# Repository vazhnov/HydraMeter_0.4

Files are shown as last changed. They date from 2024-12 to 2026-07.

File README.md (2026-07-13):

# HydraMeter_0.4

Open source [multimeter](https://en.wikipedia.org/wiki/Multimeter)

## Intro

I don't have detailed assembly documents yet, and this isn't really well made for easy assembly in any case, it's a proof of concept at the moment.

There are some more details here: https://hackaday.io/project/176607-hydrameter but it's not much. Mainly a few entries down there's a tour
of how the analog stuff works: https://hackaday.io/project/176607-hydrameter/log/223270-schematic-and-operation

## Repository structure

* Directory [MMTR_AFE_00_04_TORELEASE](./MMTR_AFE_00_04_TORELEASE) contains all schematics and board layouts.
* Directory [MMTR_V00_03_Case](./MMTR_V00_03_Case) contains all the CAD, source type is solidedge (they have a free community edition).
* Directory [Code -> HackBoard_V02_10_shbrd_cal](./Code/HackBoard_V02_10_shbrd_cal/) contains the code for the analog frontend.
* Directory [Code -> Display_VP_10_WirelessV2_SC](./Code/Display_VP_10_WirelessV2_SC/) contains code for the display section.

## Notes

I would recommend 24 to 28 AWG stranded wire for connecting to switches, except the mA/uA switch, for which I'd use 20AWG.
The switches should pull inputs to the 74165s to ground, for numbering you'll have to check the code (or adjust it), when assembled I just
wired up all of them then recorded which switch went where, I don't have a list or diagram. On the board these are labeled A-H, one set
is near the middle of the board, the other next to the module connector.

Hardwired connections are: the two ohms jumpers (J7 and J8) are wired to the second pole of the lower-right switch (right from the front),
and the mA/uA switch goes to J5 and J6.

There's a hardwired connection from J30 to J34, which should be made with at least 18AWG wire, as it carries the full current for the 10A range.

## Tweaks

Note that this version of the PCB has some tweaks from the last manufactured version,
these have not been verified to work.

The as-made PCB is under version 0.3,
however, this version requires significant manual rework including:
* pullup resistors for all switches to D3V3
* cutting jumpers to the Module outputs (J96-99, to configure them as inputs), and wiring switches to them
* additional capacitors on D3V3 to D0V, to stabilize the rail when using a radio module
* DNP U5, and bridge pin 3 to pin 4
* DNP: R74, D5, C72, R76, R77, U26, R78, Q20, Q21, R80, R79
* Replace R33 with a ~16K resistor, or two 33K in parallel
* Manually cut the trace going to pin 10 on U12, U13 and U16 (pulling it to D0V), and wire that pin on the chip to D3V3
* U18 has the wrong footprint (SOIC-16 used on the board, the actual chip is a SOIC-14).
* Angle U18 such that only pins 14-9 make contact with the board (so pins 1-7 are above the surface), and solder in place.
* Then manually wire pins 2-7 to the appropriate pads with short wires.
* If using a battery, a protected cell must be used, there is no circuitry onboard to protect from over or under voltage.
* Positive should be soldered to J10, negative to J11.

To charge, two diodes can be placed in series from VBUS on the
PI pico (MCU_VBUS) to battery positive (charging the battery when USB is plugged in). Bypassing one of the diodes with
a 50 or 100 ohm resistor can improve charge time. This however WILL overcharge the battery if proper cell protection
is not in place! This is a terrible hack solution I used to get something working in like an hour. Use a charger IC
or board or something.

## License

This project uses the CERN Open Hardware Licence Version 2 - Strongly Reciprocal.
Any derived works must fall under the same license and must be open source themselves.

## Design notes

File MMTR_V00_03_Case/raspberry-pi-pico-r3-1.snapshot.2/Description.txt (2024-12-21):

Raspberry Pi Pico-R3

Link to CAD models:
https://grabcad.com/library/raspberry-pi-pico-r3-1

The first micro controller offered from the Raspberry Pi foundation. 

The software support and documentation are solid.  I will try to use it in a few projects.
https://www.raspberrypi.org/products/raspberry-pi-pico/

It's nice that it is programmable in both MicroPython and C++.
MicroPython files can be dragged and dropped to work right away, but I'm not sure if the same can be done for C/C++ files.

I was hoping for better deep sleep currents and idle power usage and also WiFi like the ESP32. Also a USB Type C connector in 2021 would have been nice.

I hope they take inspiration from the Tiny Pico (low power usage ESP32) and its good low power features.

https://www.tinypico.com/

#CAD #SolidWorks #3dmodel #microcontroller #raspberrypipico

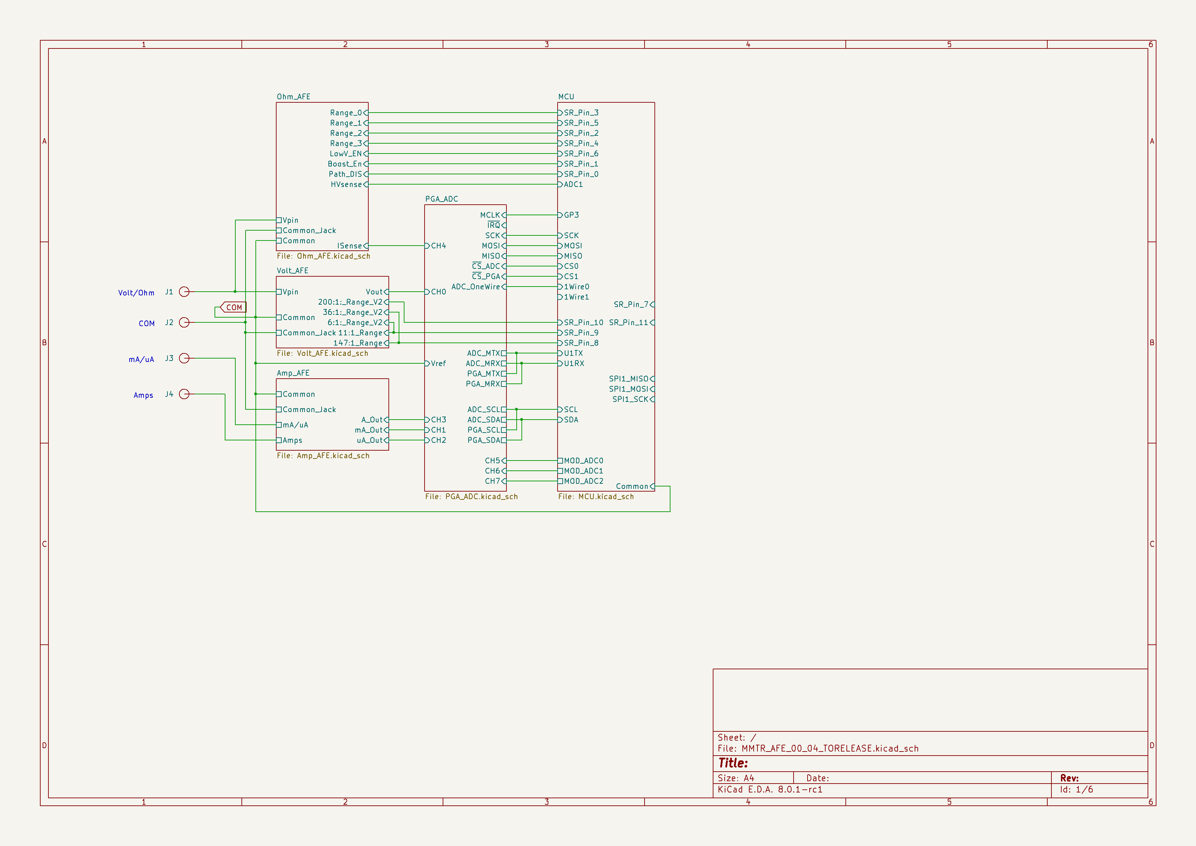
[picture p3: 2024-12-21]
MMTR_AFE_00_04_TORELEASE/Schematic_PDF_and_Pics/Root.png

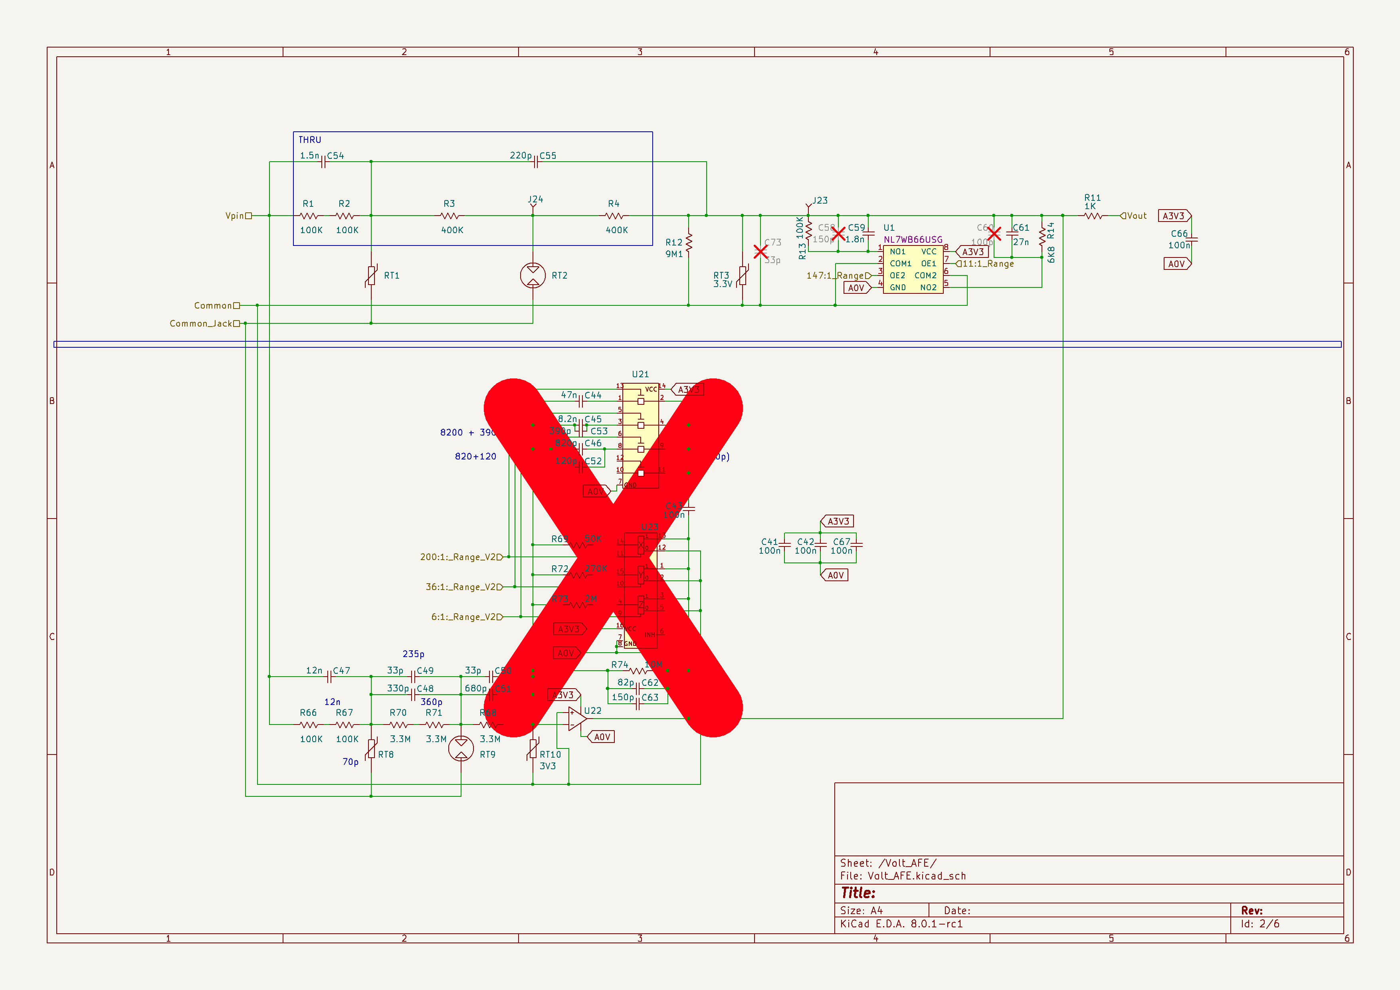
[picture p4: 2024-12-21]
MMTR_AFE_00_04_TORELEASE/Schematic_PDF_and_Pics/Volt_AFE.png

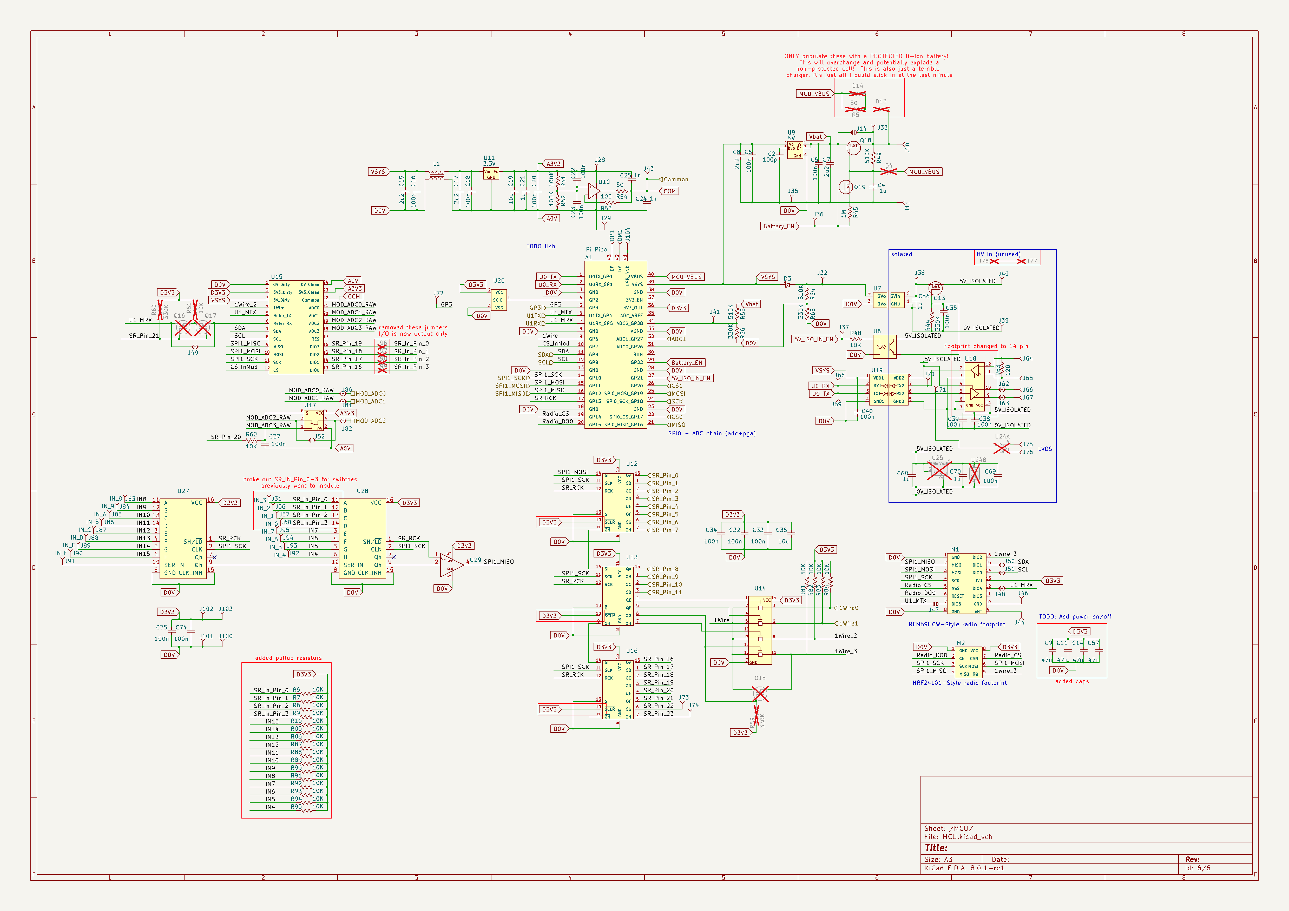
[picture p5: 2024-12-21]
MMTR_AFE_00_04_TORELEASE/Schematic_PDF_and_Pics/MCU.png

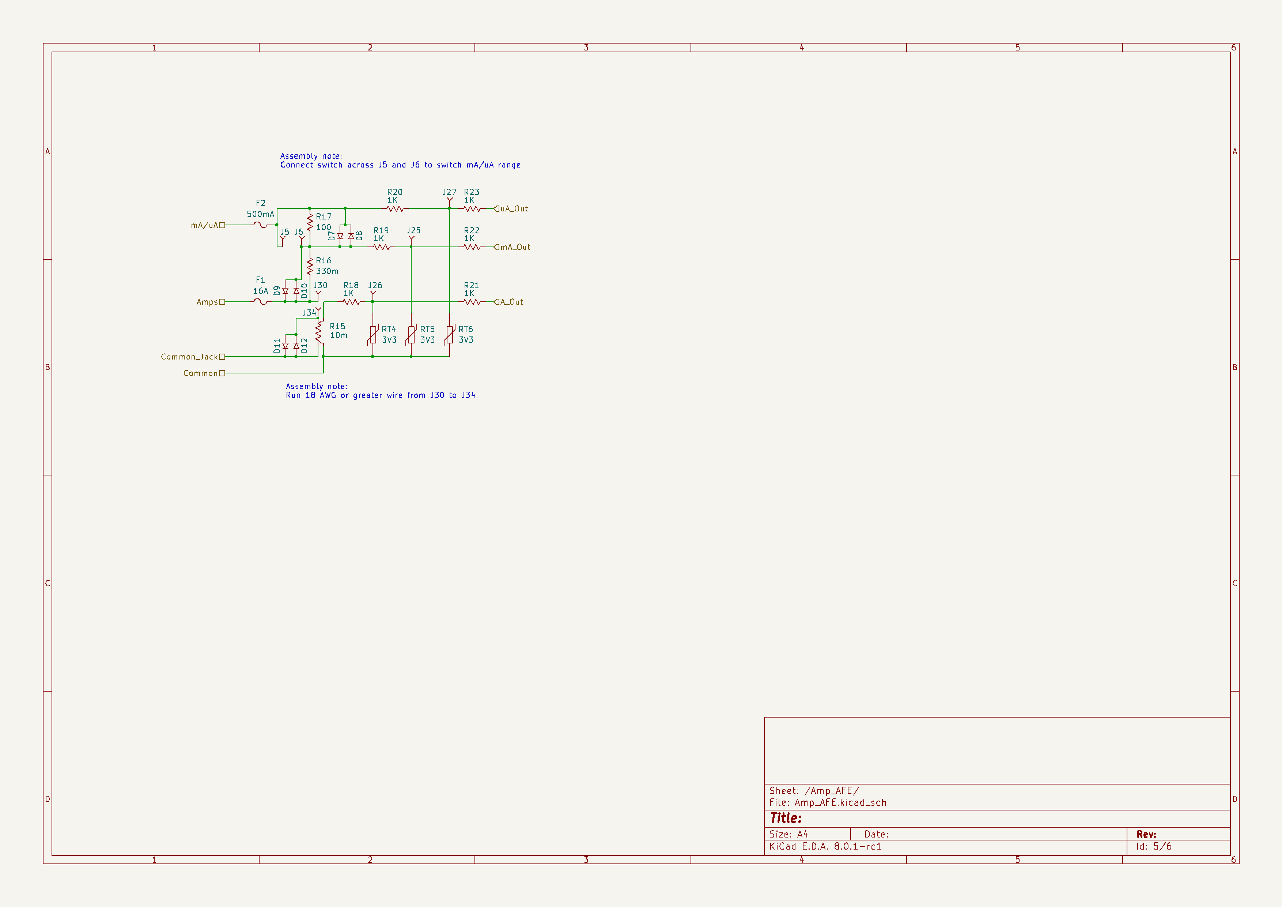
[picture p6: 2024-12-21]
MMTR_AFE_00_04_TORELEASE/Schematic_PDF_and_Pics/Amp_AFE.png

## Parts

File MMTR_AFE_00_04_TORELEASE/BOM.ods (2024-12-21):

Quantity | Digi-Key Part # | Manufacturer Part Number | Description | Unit Price | Extended
2 | 283-MSMA2512R0100FENCT-ND | MSMA2512R0100FEN | RES 0.01 OHM 1% 2W 2512 | $0.57000 | $1.14
4 | CG0603MLU-3.3ECT-ND | CG0603MLU-3.3E | VARISTOR 0603 | $0.35800 | $1.43
1 | 495-2596-1-ND | B72510T0110K062 | VARISTOR 18V 120A 0805 | $0.42000 | $0.42
1 | MCP6S28-I/SL-ND | MCP6S28-I/SL | IC OPAMP PGA 8 CIRCUIT 16SOIC | $3.04000 | $3.04
1 | 150-MCP3461R-E/ST-ND | MCP3461R-E/ST | IC ADC 16BIT SIGMA-DELTA 20TSSOP | $2.38000 | $2.38
1 | 1528-1066-ND | 1206 | SMT ADAPTERS 3 PACK 20SOIC/TSSOP | $4.50000 | $4.50
2 | DMP3099L-7DICT-ND | DMP3099L-7 | MOSFET P-CH 30V 3.8A SOT23 | $0.25200 | $0.50
6 | 4878-MMFTP84CT-ND | MMFTP84 | MOSFET P-CH 60V 130MA SOT23-3 | $0.17800 | $1.07
6 | MMBT3904TPMSCT-ND | MMBT3904-TP | TRANS NPN 40V 0.2A SOT23 | $0.09000 | $0.54
10 | 2N3904TAFSCT-ND | 2N3904TA | TRANS NPN 40V 0.2A TO92-3 | $0.28300 | $2.83
1 | 2725-B0309S-1WR3-ND | B0309S-1WR3 | DC DC CONVERTER 9V 1W | $1.82000 | $1.82
1 | 2725-B0305S-1WR3-ND | B0305S-1WR3 | DC DC CONVERTER 5V 1W | $1.82000 | $1.82
1 | 31-AP7375-33SA-7CT-ND | AP7375-33SA-7 | IC REG LIN 3.3V 300MA SOT23-3 | $0.41000 | $0.41
1 | 945-3159-ND | RFM-0505S | DC DC CONVERTER 5V 1W | $1.95000 | $1.95
1 | 2648-SC0915CT-ND | SC0915 | RASPBERRY PI PICO RP2040 | $4.00000 | $4.00
1 | LMR321G-GCT-ND | LMR321G-GTR | IC OPAMP GP 1 CIRCUIT 5SSOP | $0.45000 | $0.45
1 | 576-2575-1-ND | LMC7101BYM5-TR | IC OPAMP GP 1 CIRCUIT SOT23-5 | $0.62000 | $0.62
2 | A105968CT-ND | YR1B100KCC | RES 100K OHM 0.1% 1/4W AXIAL | $0.52300 | $1.05
1 | YAG1966CT-ND | RT0805BRD076K8L | RES SMD 6.8K OHM 0.1% 1/8W 0805 | $0.36000 | $0.36
1 | 311-9.10MFRCT-ND | RC1206FR-079M1L | RES 9.1M OHM 1% 1/4W 1206 | $0.03600 | $0.04
1 | 495-6548-1-ND | B72205S0231K311 | VARISTOR 360V 400A DISC 5MM | $0.46000 | $0.46
1 | 495-3205-ND | B32671L1152J000 | CAP FILM 1500PF 5% 1.6KVDC RAD | $0.60000 | $0.60
1 | 493-3481-ND | QYX2A272JTP | CAP FILM 2700PF 5% 100VDC RADIAL | $0.33000 | $0.33
1 | 486-7110-1-ND | 34.6062 | FUSE BOARD MNT 63MA 250VAC RAD | $0.38000 | $0.38
1 | 486-3324-ND | 8020.508 | FUSE CERAMIC 16A 500VAC 400VDC | $0.90000 | $0.90
4 | 507-FC-102BRIGHTTIN-ND | FC-102 BRIGHT TIN | FUSE CLIP CARTRIDGE 15A PCB | $0.18600 | $0.74
1 | 13-RT1206FRD07100RLCT-ND | RT1206FRD07100RL | RES SMD 100 OHM 1% 1/4W 1206 | $0.12700 | $0.13
1 | 738-RNCF1206DTE1R00CT-ND | RNCF1206DTE1R00 | RES 1 OHM 0.5% 1/4W 1206 | $0.33000 | $0.33
1 | BKCT2912-0-ND | CT2912-0 | CONN BANANA JACK SOLDER BLACK | $1.40000 | $1.40
3 | BKCT2912-2-ND | CT2912-2 | CONN BANANA JACK SOLDER RED | $1.40000 | $4.20
1 | 497-STISO621TRCT-ND | STISO621TR | DUAL CHANNEL DIGITAL ISOLATOR | $2.29000 | $2.29
1 | 36-2478-ND | 2478 | BATT HOLDER AA 4 CELL 6" LEADS | $1.97000 | $1.97
1 | NL7WB66USGOSCT-ND | NL7WB66USG | IC SWITCH SPST-NO X 2 10OHM US8 | $0.39000 | $0.39
1 | 160-1360-5-ND | LTV-816 | OPTOISOLATR 5KV TRANSISTOR 4-DIP | $0.390 | $0.39
1 | AP2210K-5.0TRG1DICT-ND | AP2210K-5.0TRG1 | IC REG LINEAR 5V 300MA SOT23-5 | $0.440 | $0.44
1 | 4816-WCM2012F2SF-361T03CT-ND | WCM 2012F2SF-361T03 | 2 LINE COMMON MODE CHOKE SURFACE | $0.120 | $0.12
10 | 1276-1075-1-ND | CL31A106KAHNNNE | CAP CER 10UF 25V X5R 1206 | $0.128 | $1.28
3 | CUS08F30H3FCT-ND | CUS08F30,H3F | DIODE SCHOTTKY 30V 800MA USC | $0.320 | $0.96
10 | DMN65D8L-7DICT-ND | DMN65D8L-7 | MOSFET N-CH 60V 310MA SOT23 | $0.124 | $1.24
1 | PI5A3157CEXCT-ND | PI5A3157CEX | IC SWITCH SPDTX1 13OHM SOT363-6 | $0.350 | $0.35
1 | 13-FMP100JT-52-1KCT-ND | FMP100JT-52-1K | RES 1K OHM 5% 1W AXIAL | $0.200 | $0.20
1 | 118-2045-14-BLF-ND | 2045-14-BLF | GDT 145V 10KA 2 POLE TH | $0.820 | $0.82
2 | 296-SN74HCS165PWRCT-ND | SN74HCS165PWR | 8-BIT PARALLEL-LOAD SHIFT REGIST | $0.450 | $0.90
1 | 74LVC1G126W5-7DICT-ND | 74LVC1G126W5-7 | IC BUFFER NON-INVERT 5.5V SOT25 | $0.310 | $0.31
2 | 1712-YR1B402KCCCT-ND | YR1B402KCC | RES 402K OHM 0.1% 1/4W AXIAL | $0.523 | $1.05
10 | 1655-1N4007FLCT-ND | 1N4007FL | DIODE GEN PURP 1KV 1A SOD123FL | $0.096 | $0.96
3 | 1727-3327-1-ND | 74HC595BQ,115 | IC 8BIT SHIFT REGISTER 16-DHVQFN | $0.353 | $1.06
1 | 1016-1834-1-ND | SP491EEN-L/TR | IC TRANSCEIVER FULL 1/1 14SOIC | $1.710 | $1.71
1 | 11AA080T-I/TTCT-ND | 11AA080T-I/TT | IC EEPROM 8KBIT SGL WIRE SOT23-3 | $0.300 | $0.30
1 | 1928-1294-ND | FKP2O102201D00JSSD | CAP FILM 220PF 5% 1KVDC RAD | $0.510 | $0.51
1 | 273-KDV12DR330ETCT-ND | KDV12DR330ET | RES 0.33 OHM 0.5% 1/2W 1206 | $0.350 | $0.35
1 | 490-6380-1-ND | GRM1885C1H182JA01J | CAP CER 1800PF 50V C0G/NP0 0603 | $0.055 | $0.06
1 | 1292-1425-1-ND | 0603B273K500CT | CAP CER 0.027UF 50V X7R 0603 | $0.052 | $0.05
1 | 495-3205-ND | B32671L1152J000 | CAP FILM 1500PF 5% 1.6KVDC RAD | $0.600 | $0.60
1 | 283-MSMA2512R0100FENCT-ND | MSMA2512R0100FEN | RES 0.01 OHM 1% 2W 2512 | $0.570 | $0.57
1 | 486-4156-ND | 8020.5068.G | FUSE CERM 1A 500VAC 500VDC 3AB | $0.660 | $0.66
1 | 2019-RN73R2BTTD5100B25CT-ND | RN73R2BTTD5100B25 | RES 510 OHM 0.1% 1/4W 1206 | $0.350 | $0.35
1 | 13-RE1206FRE0710KLCT-ND | RE1206FRE0710KL | RES SMD 10K OHM 1% 1/4W 1206 | $0.036 | $0.04
2 | 13-RT1206FRD07100KLCT-ND | RT1206FRD07100KL | RES SMD 100K OHM 1% 1/4W 1206 | $0.13 | $0.25
1 | 13-RE1206FRE071MLCT-ND | RE1206FRE071ML | RES SMD 1M OHM 1% 1/4W 1206 | $0.036 | $0.04
25 | RMCF0603FG1K00CT-ND | RMCF0603FG1K00 | RES 1K OHM 1% 1/10W 0603 | $0.009 | $0.22
25 | CR0603-FX-1002ELFCT-ND | CR0603-FX-1002ELF | RES SMD 10K OHM 1% 1/10W 0603 | $0.007 | $0.18
25 | RMCF0603FT100KCT-ND | RMCF0603FT100K | RES 100K OHM 1% 1/10W 0603 | $0.007 | $0.18
25 | RMCF0603FG1M00CT-ND | RMCF0603FG1M00 | RES 1M OHM 1% 1/10W 0603 | $0.007 | $0.18
25 | RMCF0603FT3K30CT-ND | RMCF0603FT3K30 | RES 3.3K OHM 1% 1/10W 0603 | $0.007 | $0.18
25 | RMCF0603FT33K0CT-ND | RMCF0603FT33K0 | RES 33K OHM 1% 1/10W 0603 | $0.007 | $0.18
25 | RMCF0603FT330KCT-ND | RMCF0603FT330K | RES 330K OHM 1% 1/10W 0603 | $0.007 | $0.18
25 | RMCF0603FT510KCT-ND | RMCF0603FT510K | RES 510K OHM 1% 1/10W 0603 | $0.009 | $0.22
1 | Usb C adapters | Female | https://www.amazon.com/ANMBEST-Connector-Receptacle-Adapter-Support/dp/B09WCSF8FC/ref=sr_1_4
1 | RS485/422 dev board |  | https://www.amazon.com/Max485-Chip-RS-485-Module-Raspberry/dp/B00NIOLNAG/ref=sr_1_2
1 | 12864 LCD screen (ST7565) | Select Gray Screen | https://www.aliexpress.us/item/3256805974305629.html
1 | 8.5 x 13.5 Rocker Switches (5pk) | Select 8.5 x 13.5 | https://www.aliexpress.us/item/2255800845721307.html
1 | Tiny Li-po battery WITH protection circuit | Select 1 | https://www.aliexpress.us/item/3256805609393649.html
2 | Radio Module | Select NRF24L01 DIP | https://www.aliexpress.us/item/3256805987194394.html
1 | 5 pk of DPST rocker switches | Select Black No Lamp | https://www.aliexpress.us/item/3256805717784088.html
4 | DPDT rocker switches | Select 6 pin On-Off-On | https://www.aliexpress.us/item/3256803299490563.html
1 | SPDT Momentary Rocker switch | Select 3 pin Self reset | https://www.aliexpress.us/item/3256803299490563.html

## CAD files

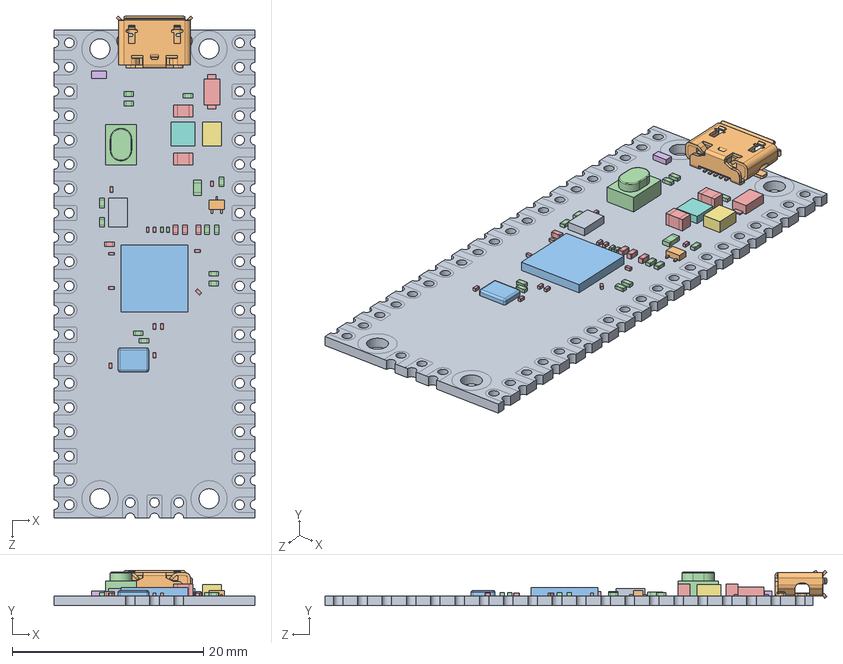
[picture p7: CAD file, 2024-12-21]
MMTR_V00_03_Case/raspberry-pi-pico-r3-1.snapshot.2/Raspberry Pi Pico-R3.SLDASM
21.0 x 3.69 x 52.4 mm
PCB, Raspberry Pi Pico-R3
MicroUSB Port, Raspberry Pi Pico-R3
RP2040 Microcontroller, Raspberry Pi Pico-R3
SW1, Tact Switch, Raspberry Pi Pico-R3
D1, Diode, Schottky, Raspberry Pi Pico-R3
D2, QSME-C194, LED, Raspberry Pi Pico-R3
L1, Inductor, Raspberry Pi Pico-R3
U2, RT6150B-33GQW, Buck Boost Converter, Raspberry Pi Pico-R3
U3, W25Q16JVUXIQ, Serial NOR Flash 16 Mbit, Raspberry Pi Pico-R3
Q1, MOSFET, DMG1012T, Raspberry Pi Pico-R3
X1, X12M000000S096, 12 Mhz Crystal Resonator, Raspberry Pi Pico-R3
SMD Resistor, Configurable, Raspberry Pi Pico-R3 x 15
SMD Capacitor, Configurable, Raspberry Pi Pico-R3 x 18

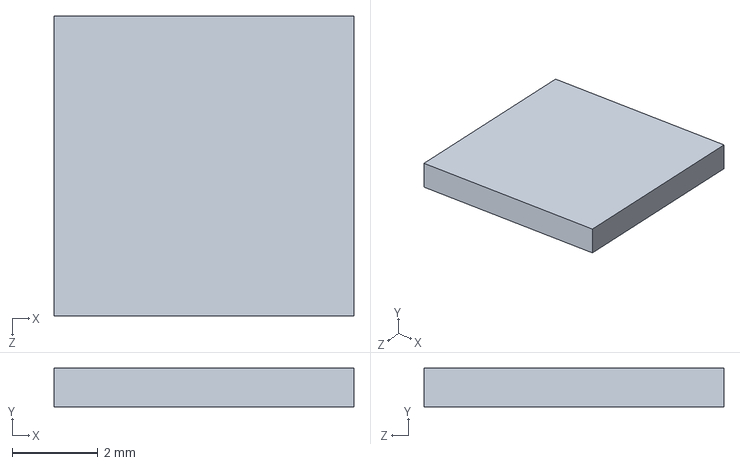
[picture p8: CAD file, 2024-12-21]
MMTR_V00_03_Case/raspberry-pi-pico-r3-1.snapshot.2/RP2040 Microcontroller, Raspberry Pi Pico-R3.SLDPRT
7.00 x 0.9 x 7.00 mm

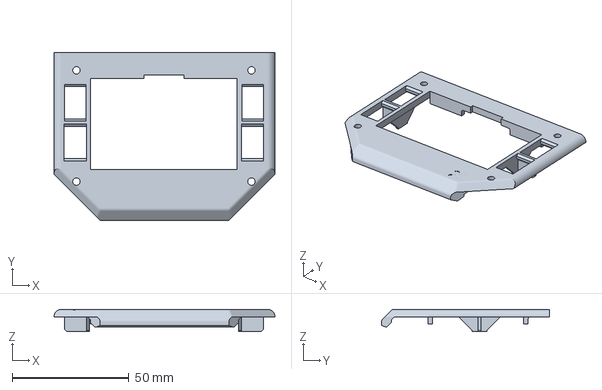
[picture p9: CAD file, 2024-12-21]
MMTR_V00_03_Case/ScreenCover_00_03_24_10_24_125.3mf
94.6 x 71.9 x 9.52 mm

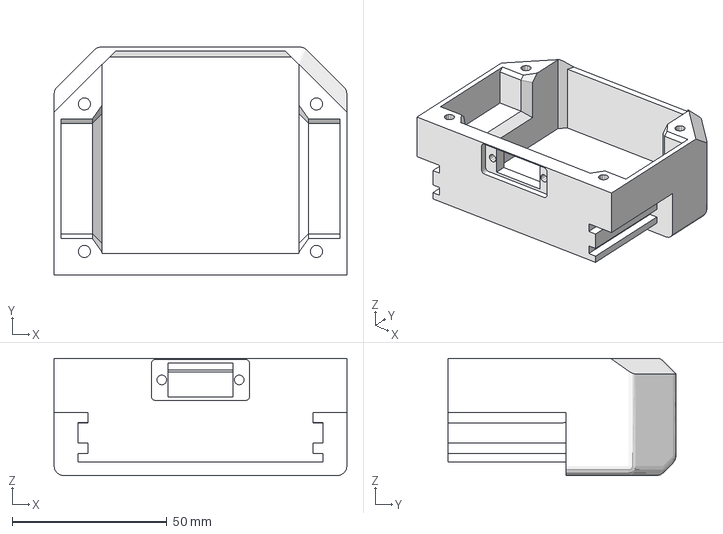
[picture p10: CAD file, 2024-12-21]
MMTR_V00_03_Case/Case_Upper_Dovetail_00_03_24_10_15_1353.3mf
94.6 x 73.7 x 37.9 mm

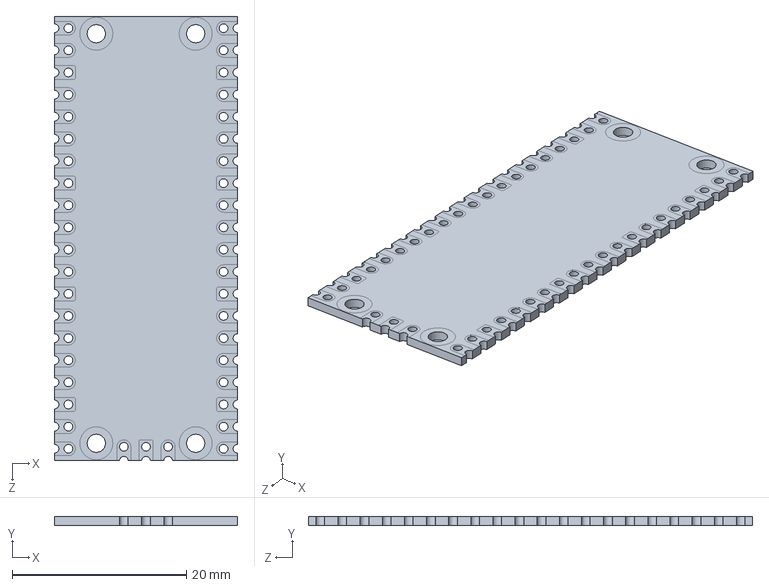
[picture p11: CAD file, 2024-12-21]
MMTR_V00_03_Case/raspberry-pi-pico-r3-1.snapshot.2/PCB, Raspberry Pi Pico-R3.SLDPRT
21.0 x 1.00 x 51.0 mm

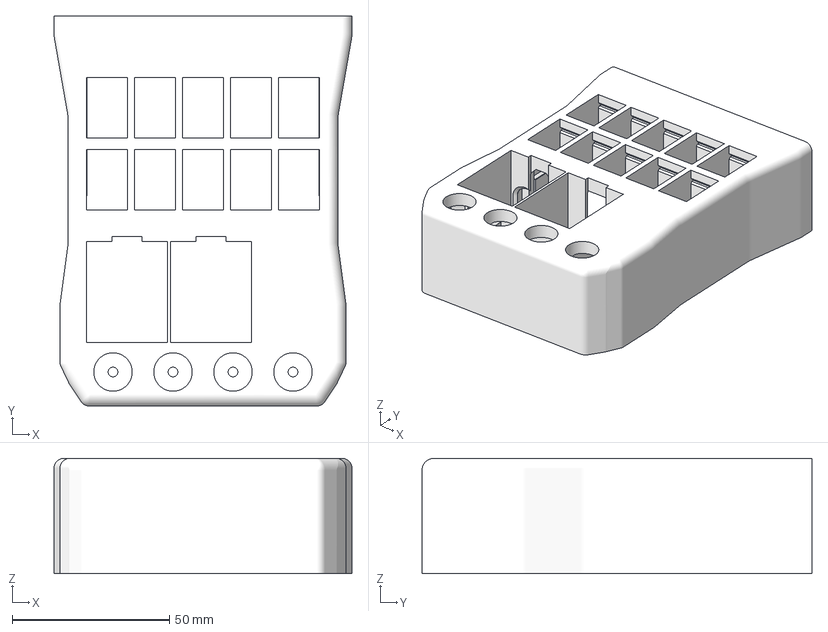
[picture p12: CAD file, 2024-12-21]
MMTR_V00_03_Case/Case_Top_00_03_24_10_16_2419.3mf
94.6 x 123.8 x 36.6 mm

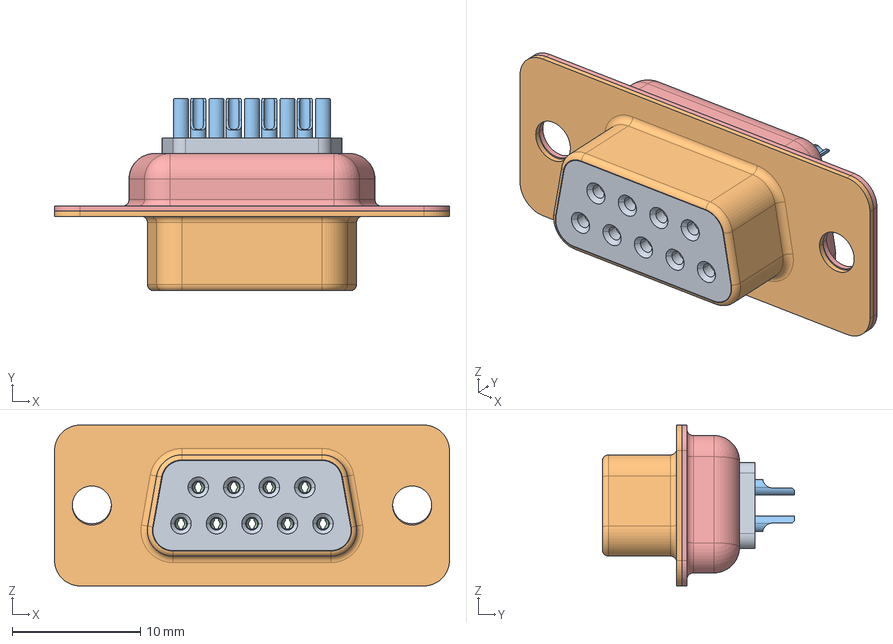
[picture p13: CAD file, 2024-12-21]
MMTR_V00_03_Case/l77sde09s-4.stp
30.8 x 15.0 x 12.6 mm
100-09HOUSING
100-09FEMALE-FRONTSHELL
104-FEMALE-TERMINAL-SHORT x 9
100-09FEMALE-BACKSHELL5555

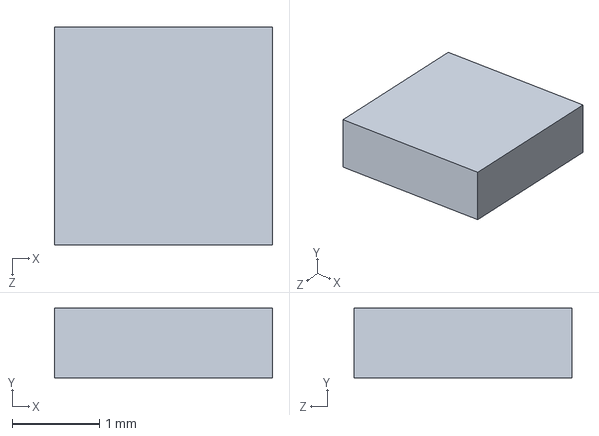
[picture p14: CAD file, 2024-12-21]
MMTR_V00_03_Case/raspberry-pi-pico-r3-1.snapshot.2/U3, W25Q16JVUXIQ, Serial NOR Flash 16 Mbit, Raspberry Pi Pico-R3.SLDPRT
2.50 x 0.8 x 2.50 mm

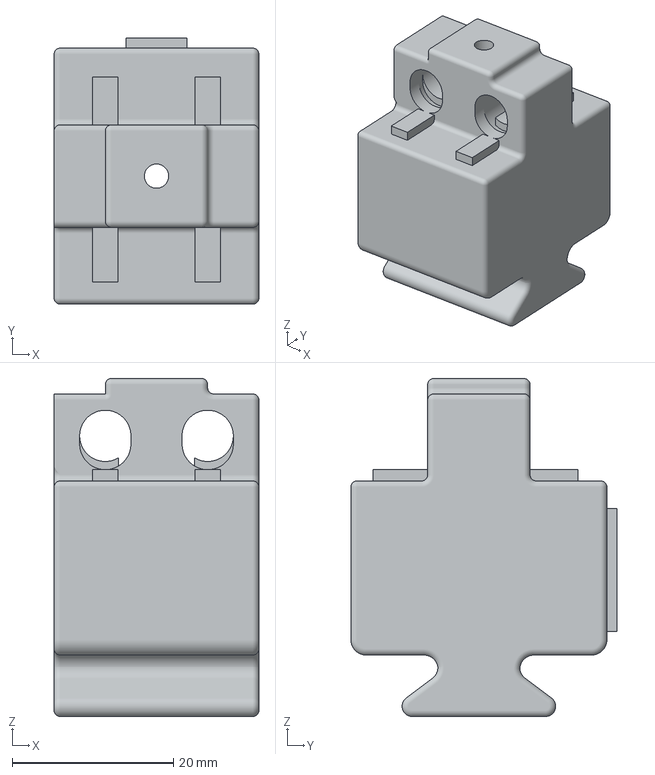
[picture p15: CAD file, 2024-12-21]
MMTR_V00_03_Case/Fuse_Holder_00_03_24_10_29.3mf
25.4 x 33.0 x 41.9 mm

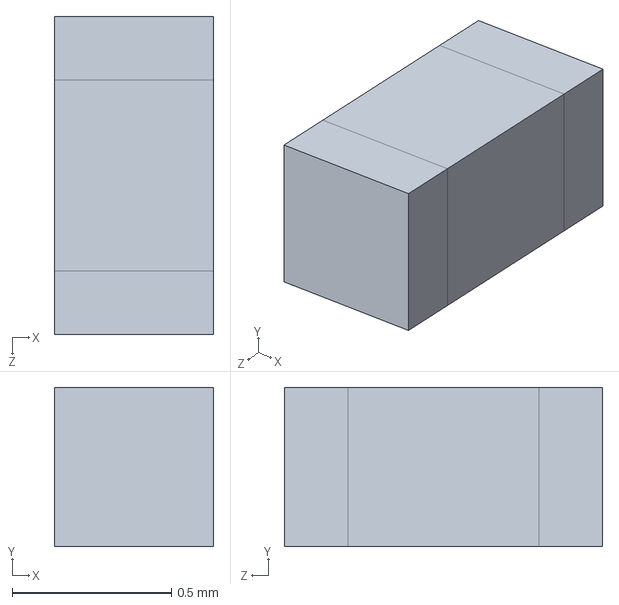
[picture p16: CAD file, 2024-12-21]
MMTR_V00_03_Case/raspberry-pi-pico-r3-1.snapshot.2/SMD Capacitor, Configurable, Raspberry Pi Pico-R3.SLDPRT
0.5 x 0.5 x 1.00 mm

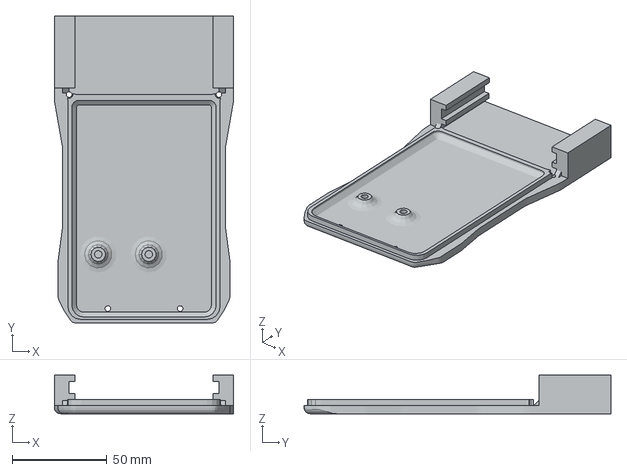
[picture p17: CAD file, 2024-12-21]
MMTR_V00_03_Case/Case_Bottom_00_03_24_10_15_1353.3mf
94.6 x 161.9 x 20.3 mm

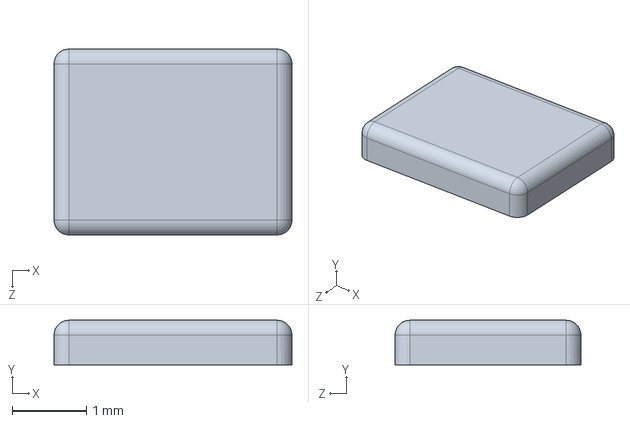
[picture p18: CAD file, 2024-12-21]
MMTR_V00_03_Case/raspberry-pi-pico-r3-1.snapshot.2/X1, X12M000000S096, 12 Mhz Crystal Resonator, Raspberry Pi Pico-R3.SLDPRT
3.20 x 0.6 x 2.50 mm

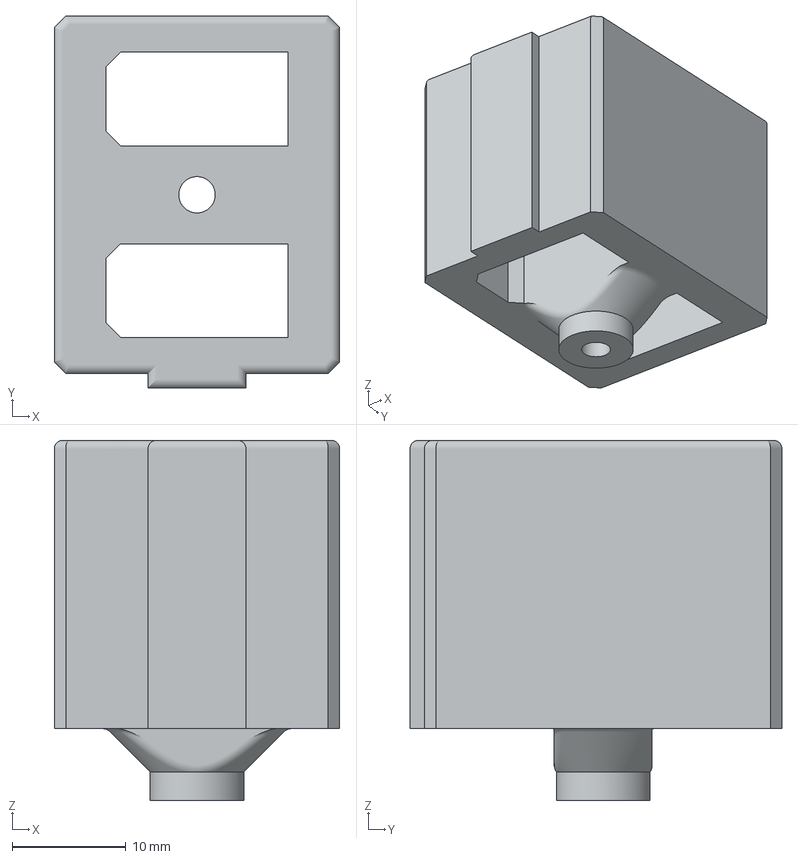
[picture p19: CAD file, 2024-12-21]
MMTR_V00_03_Case/XT60_InputMod_24_11_06.3mf
25.1 x 32.8 x 31.8 mm

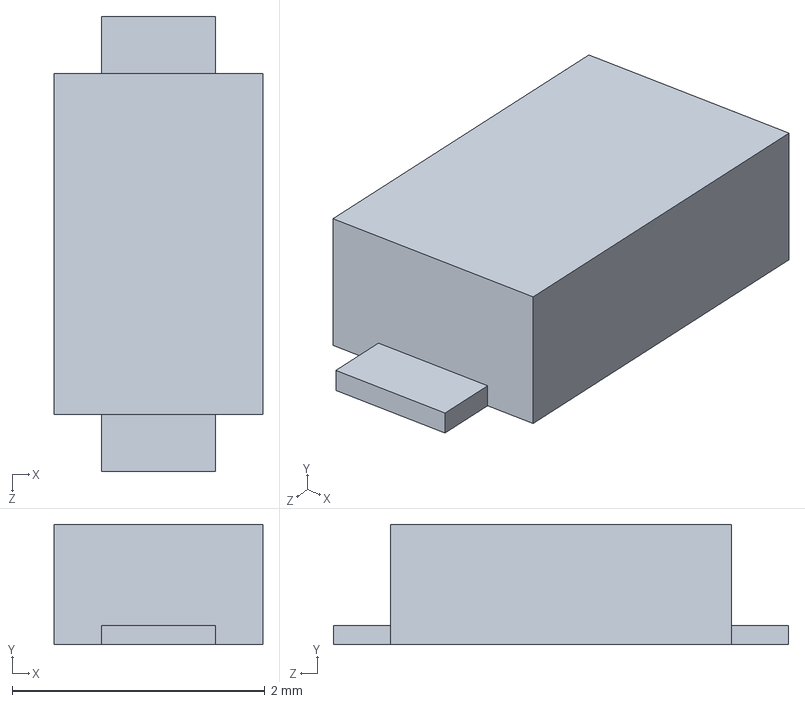
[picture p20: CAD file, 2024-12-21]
MMTR_V00_03_Case/raspberry-pi-pico-r3-1.snapshot.2/D1, Diode, Schottky, Raspberry Pi Pico-R3.SLDPRT
1.65 x 0.95 x 3.60 mm

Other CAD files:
MMTR_V00_03_Case/raspberry-pi-pico-r3-1.snapshot.2/U2, RT6150B-33GQW, Buck Boost Converter, Raspberry Pi Pico-R3.SLDPRT
MMTR_V00_03_Case/raspberry-pi-pico-r3-1.snapshot.2/SMD Resistor, Configurable, Raspberry Pi Pico-R3.SLDPRT
MMTR_V00_03_Case/raspberry-pi-pico-r3-1.snapshot.2/MicroUSB Port, Raspberry Pi Pico-R3.SLDPRT
MMTR_V00_03_Case/raspberry-pi-pico-r3-1.snapshot.2/Q1, MOSFET, DMG1012T, Raspberry Pi Pico-R3.SLDPRT
MMTR_V00_03_Case/raspberry-pi-pico-r3-1.snapshot.2/D2, QSME-C194, LED, Raspberry Pi Pico-R3.SLDPRT
MMTR_V00_03_Case/raspberry-pi-pico-r3-1.snapshot.2/L1, Inductor, Raspberry Pi Pico-R3.SLDPRT
MMTR_V00_03_Case/raspberry-pi-pico-r3-1.snapshot.2/Raspberry Pi Pico-R3.x_b
MMTR_V00_03_Case/raspberry-pi-pico-r3-1.snapshot.2/SW1, Tact Switch, Raspberry Pi Pico-R3.SLDPRT

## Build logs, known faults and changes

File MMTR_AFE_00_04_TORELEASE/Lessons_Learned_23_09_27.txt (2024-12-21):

-Pi pico form factor was not the best idea - make something surface mount and
	with IO built in, or at least use SMD footprint/headers
-Surface mount packages for modules - at least go headers or something, or make it castelations only
All those digital busses to every module is a routing nightmare
having IO expanders near the parts was useful.  Did mean giant busses, but not parallel though
Plan big digital busses during placement
Plan power/common planes during placement
Two radio modules sucks; unify
separate the 422 isolation as a module
unused space under fuses - can I do anything with that?
SMALL packages during design - soldering is fine, routing space is hard to come by

KEY THE INPUT MODULE AND FUSES
plan for switch wiring, pick for low-profile switches

Ohm-input protection leaking to main!
source follower - Vdson varied wildly with current: some kind of feedback?  Yeah did some spice in mid-nov
--Solved by just changing the input resistors to pull gate further down

Not enough switches on the display, at least need d pad
input noise filtering (switchable?) maybe even hardware AC.  At least low-pass
buffer the voltage afte the first input, then switches don't need high spec
Probably get rid of PGA as it is, either use ADC or a simpler mux/buffer.  Maybe noise improvement?

The radio burst power is weird, add switching and caps, probably
oh wait no because parasitic on pins, probably vsys?  Something to let programming be normal...

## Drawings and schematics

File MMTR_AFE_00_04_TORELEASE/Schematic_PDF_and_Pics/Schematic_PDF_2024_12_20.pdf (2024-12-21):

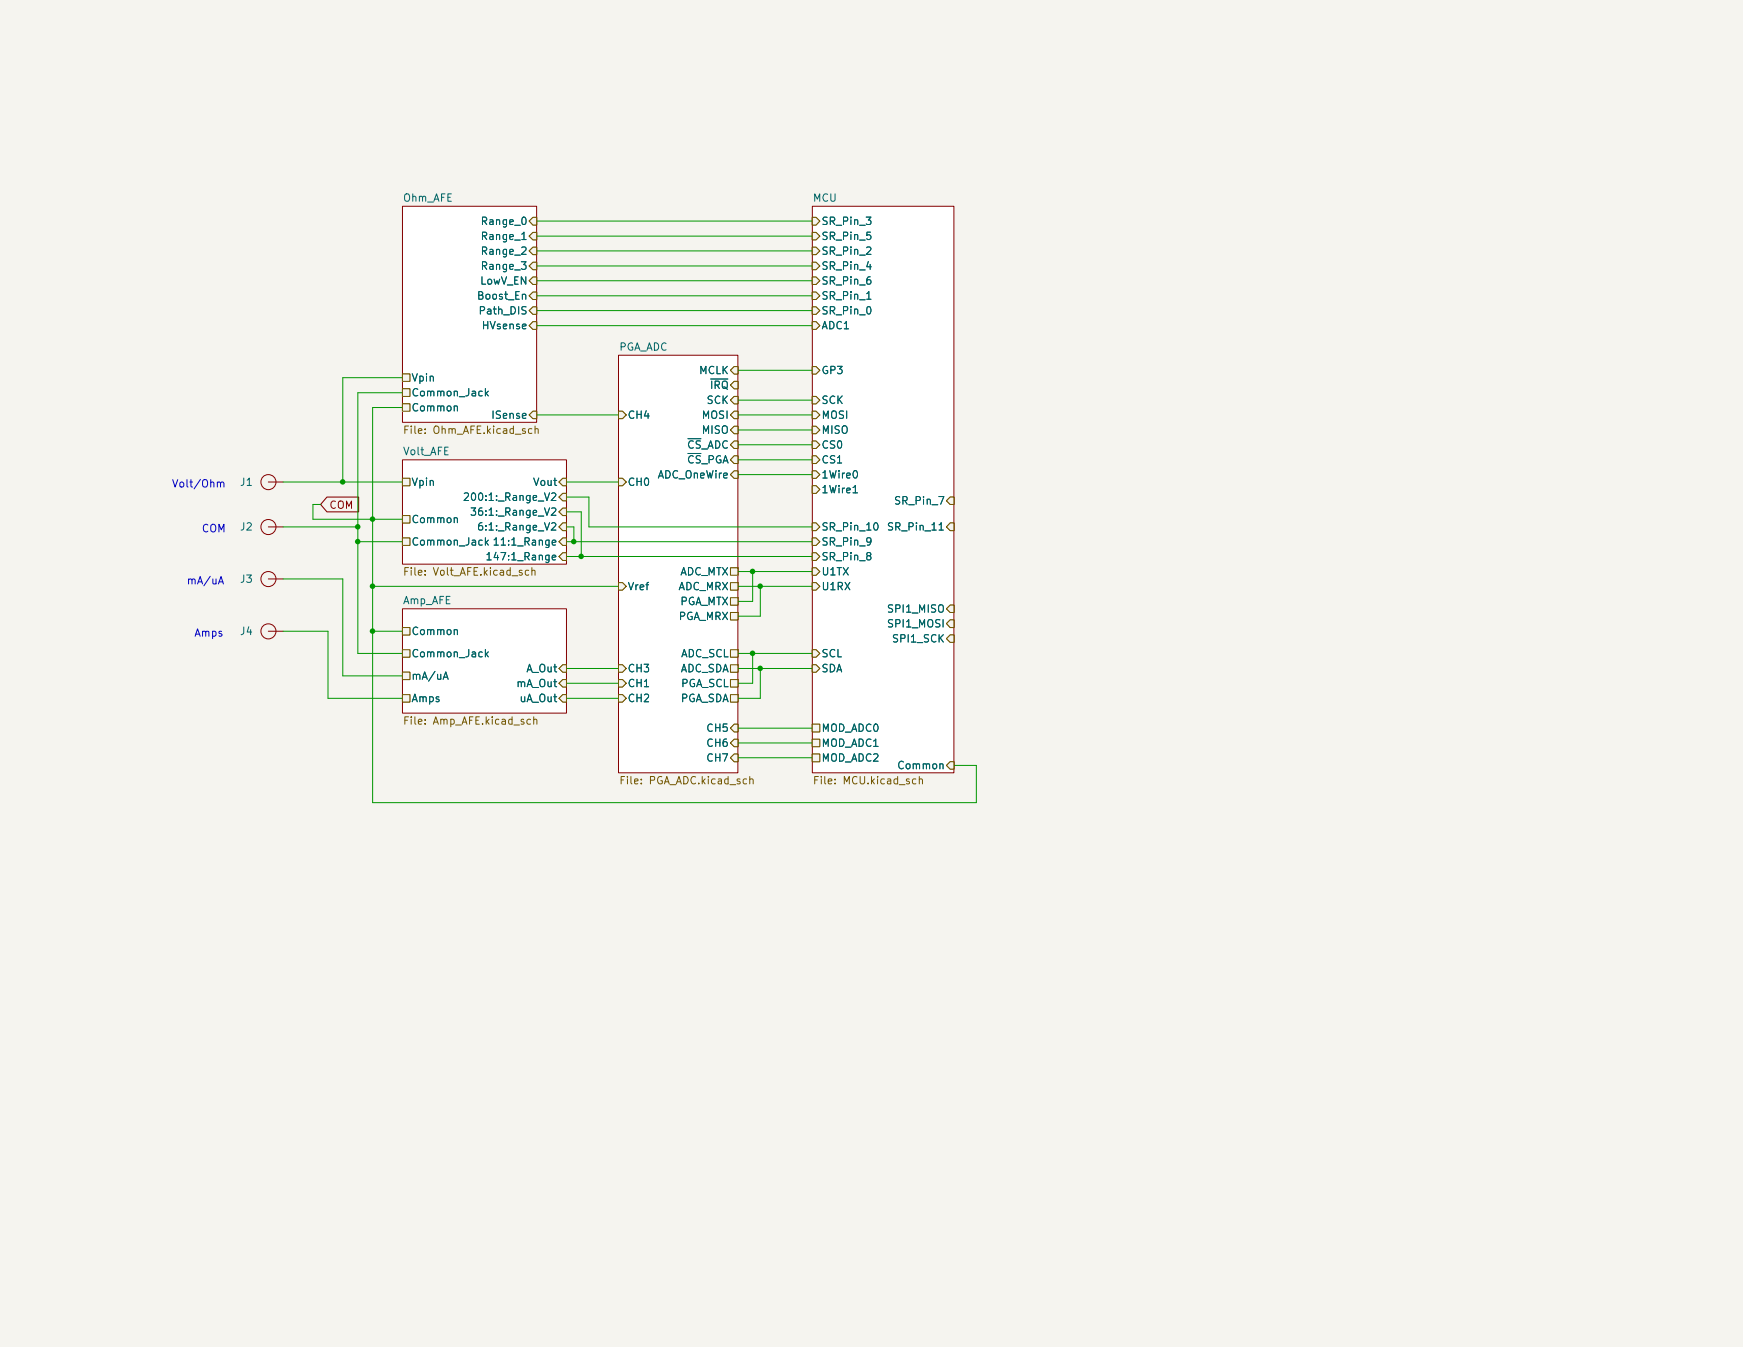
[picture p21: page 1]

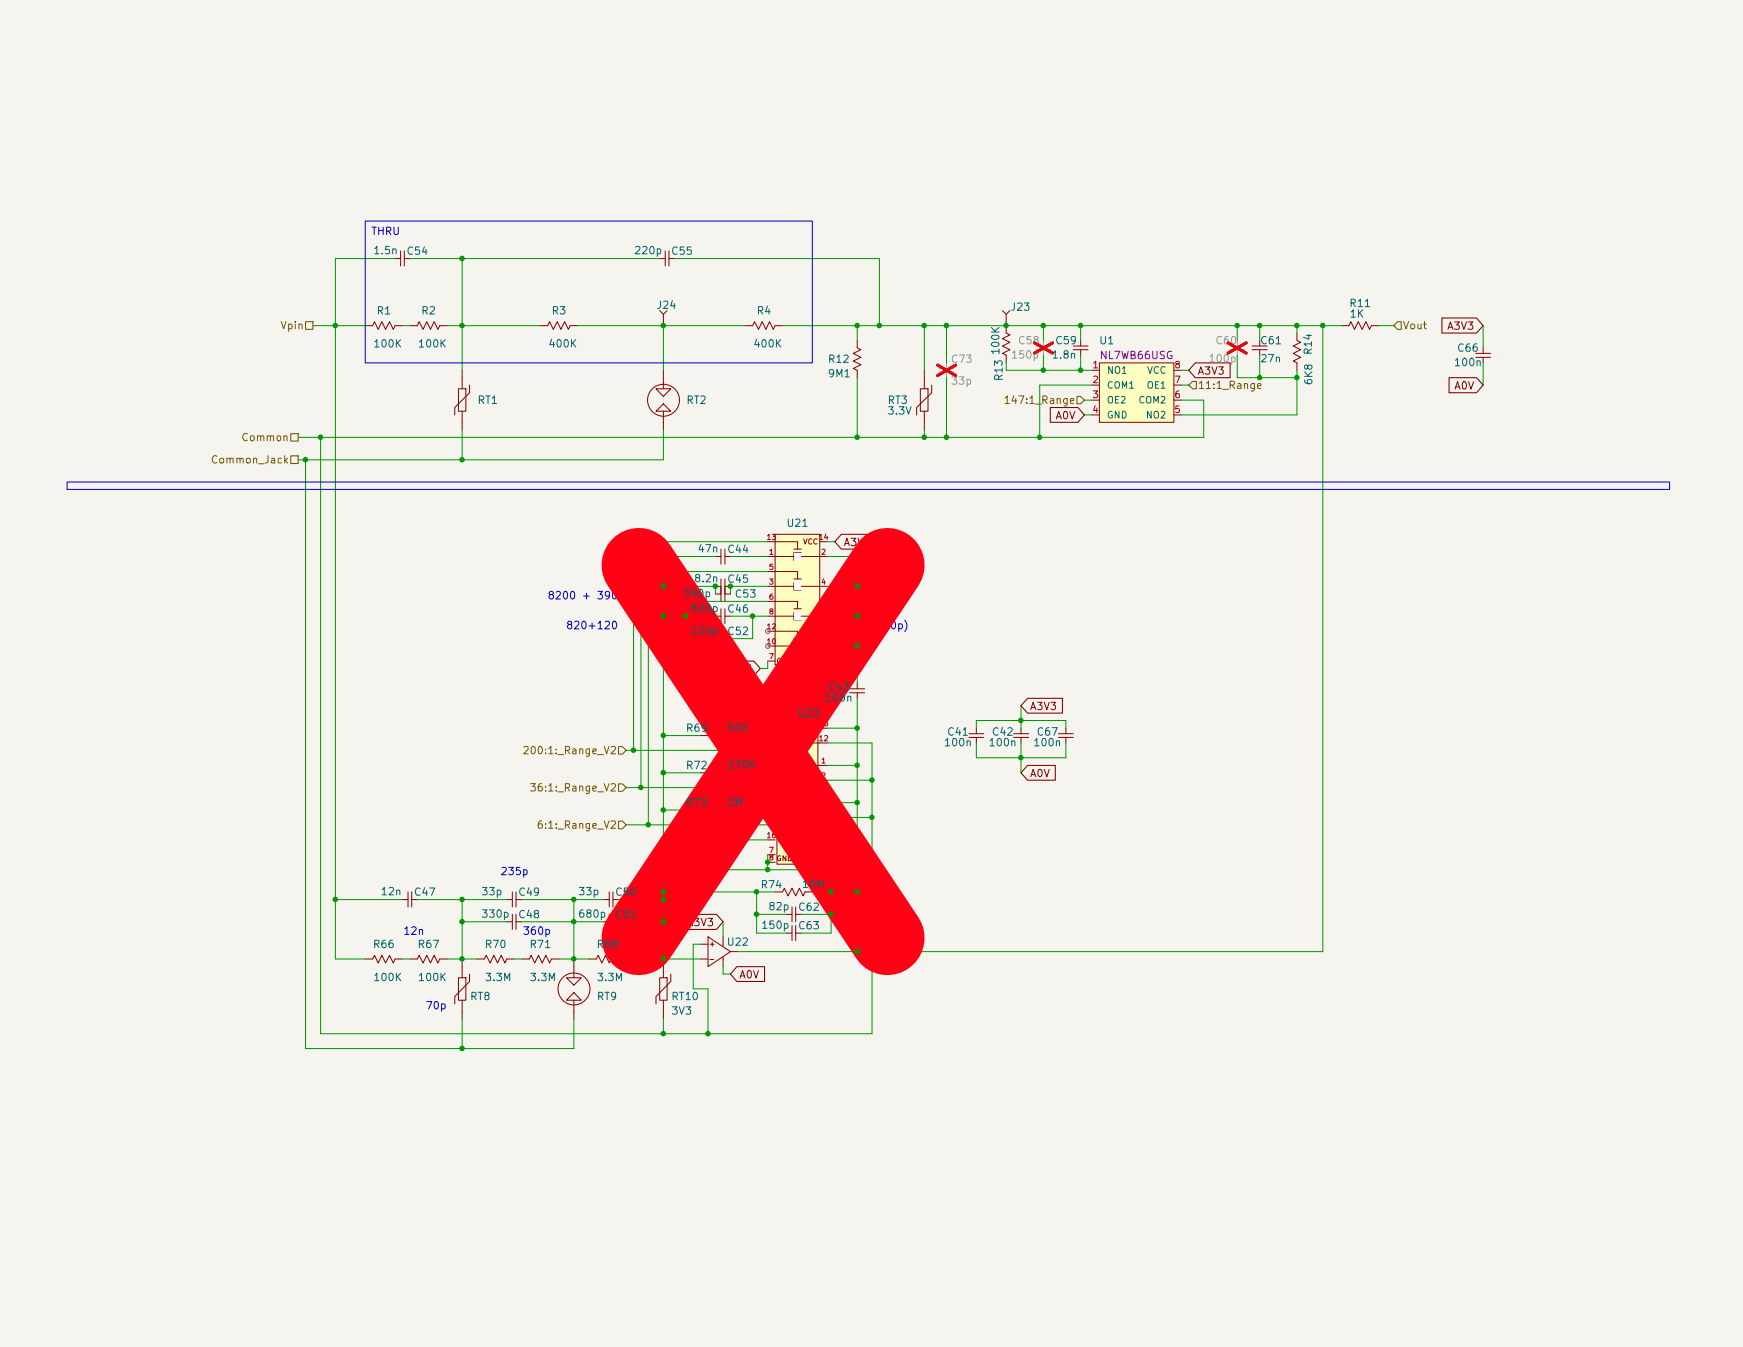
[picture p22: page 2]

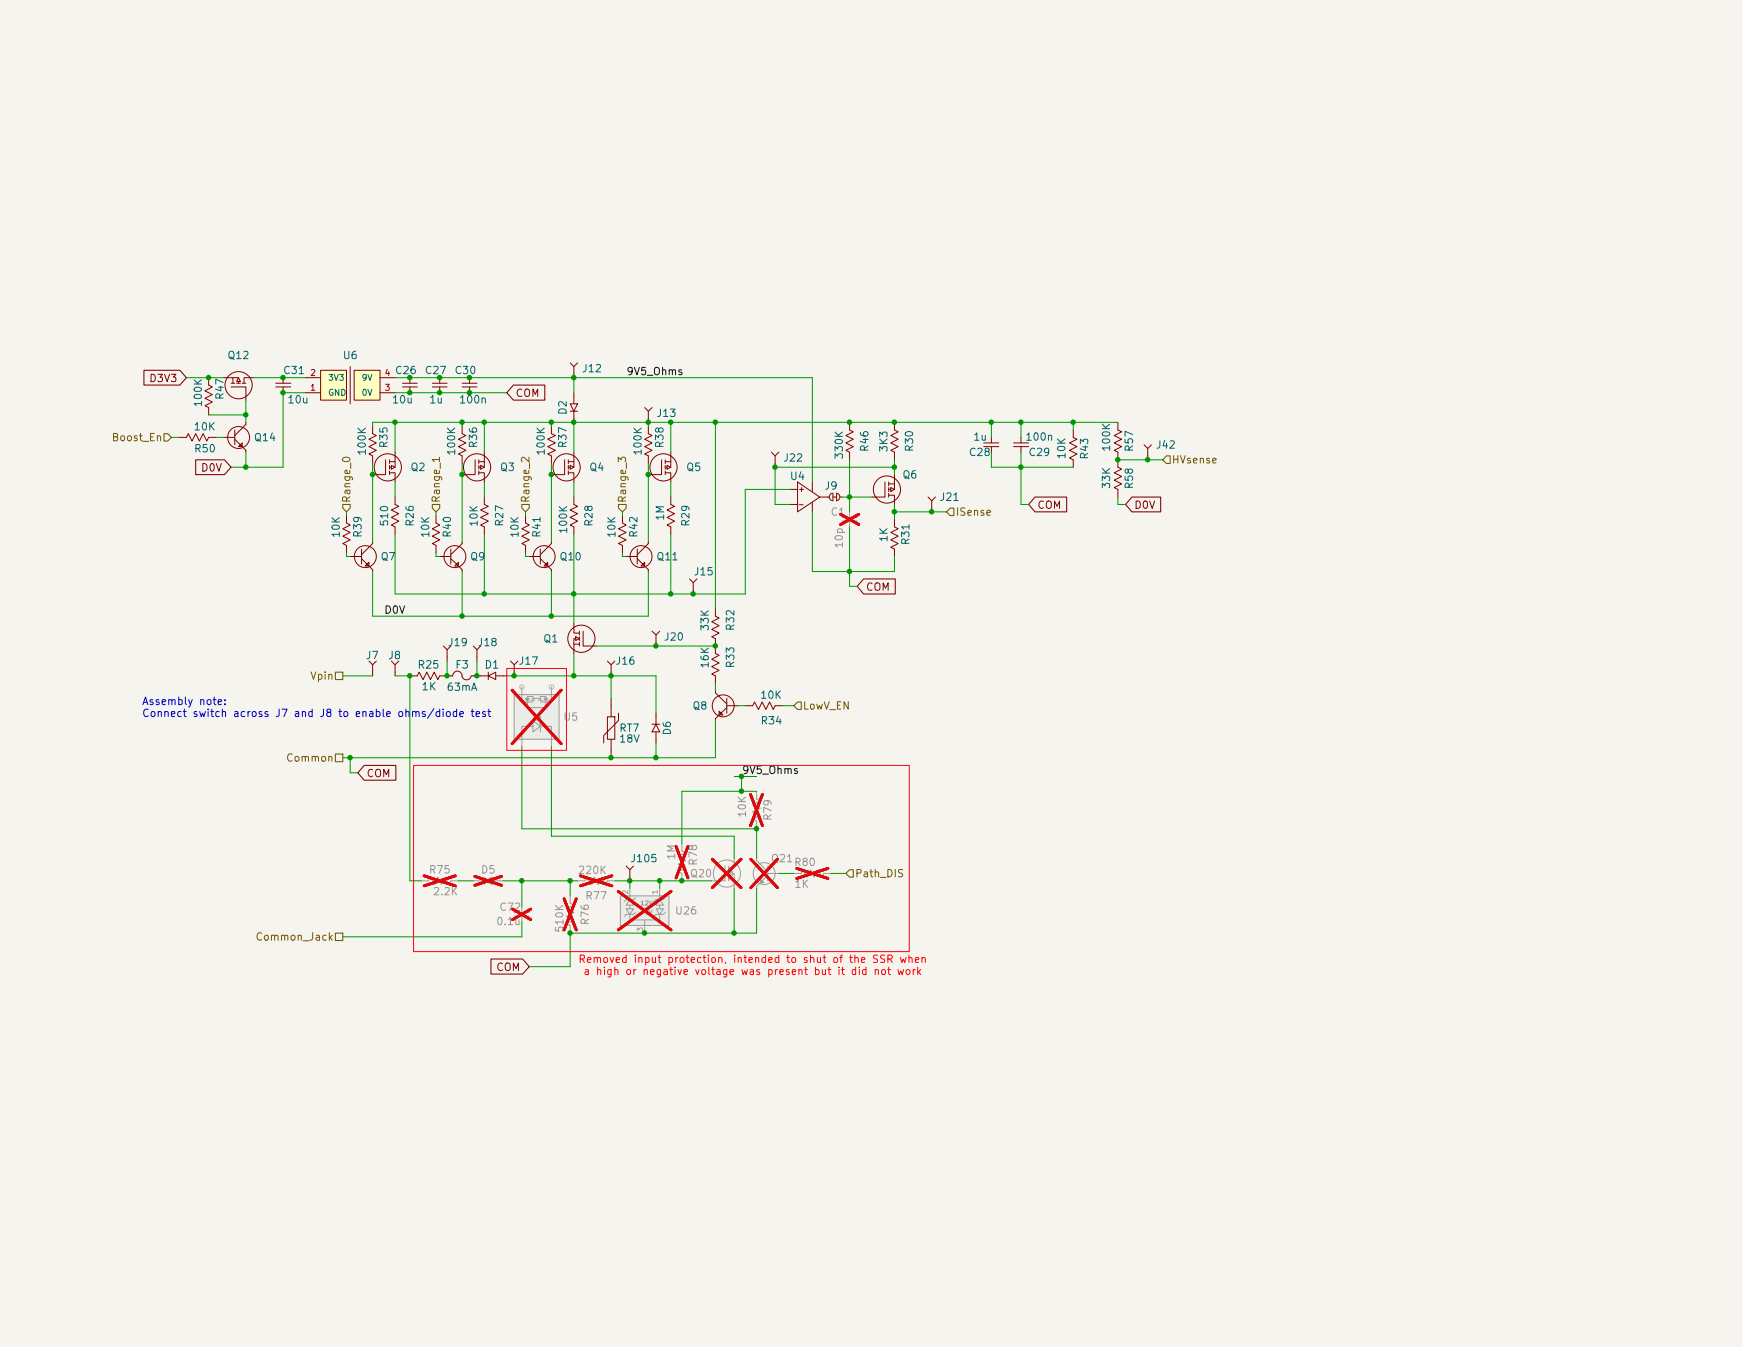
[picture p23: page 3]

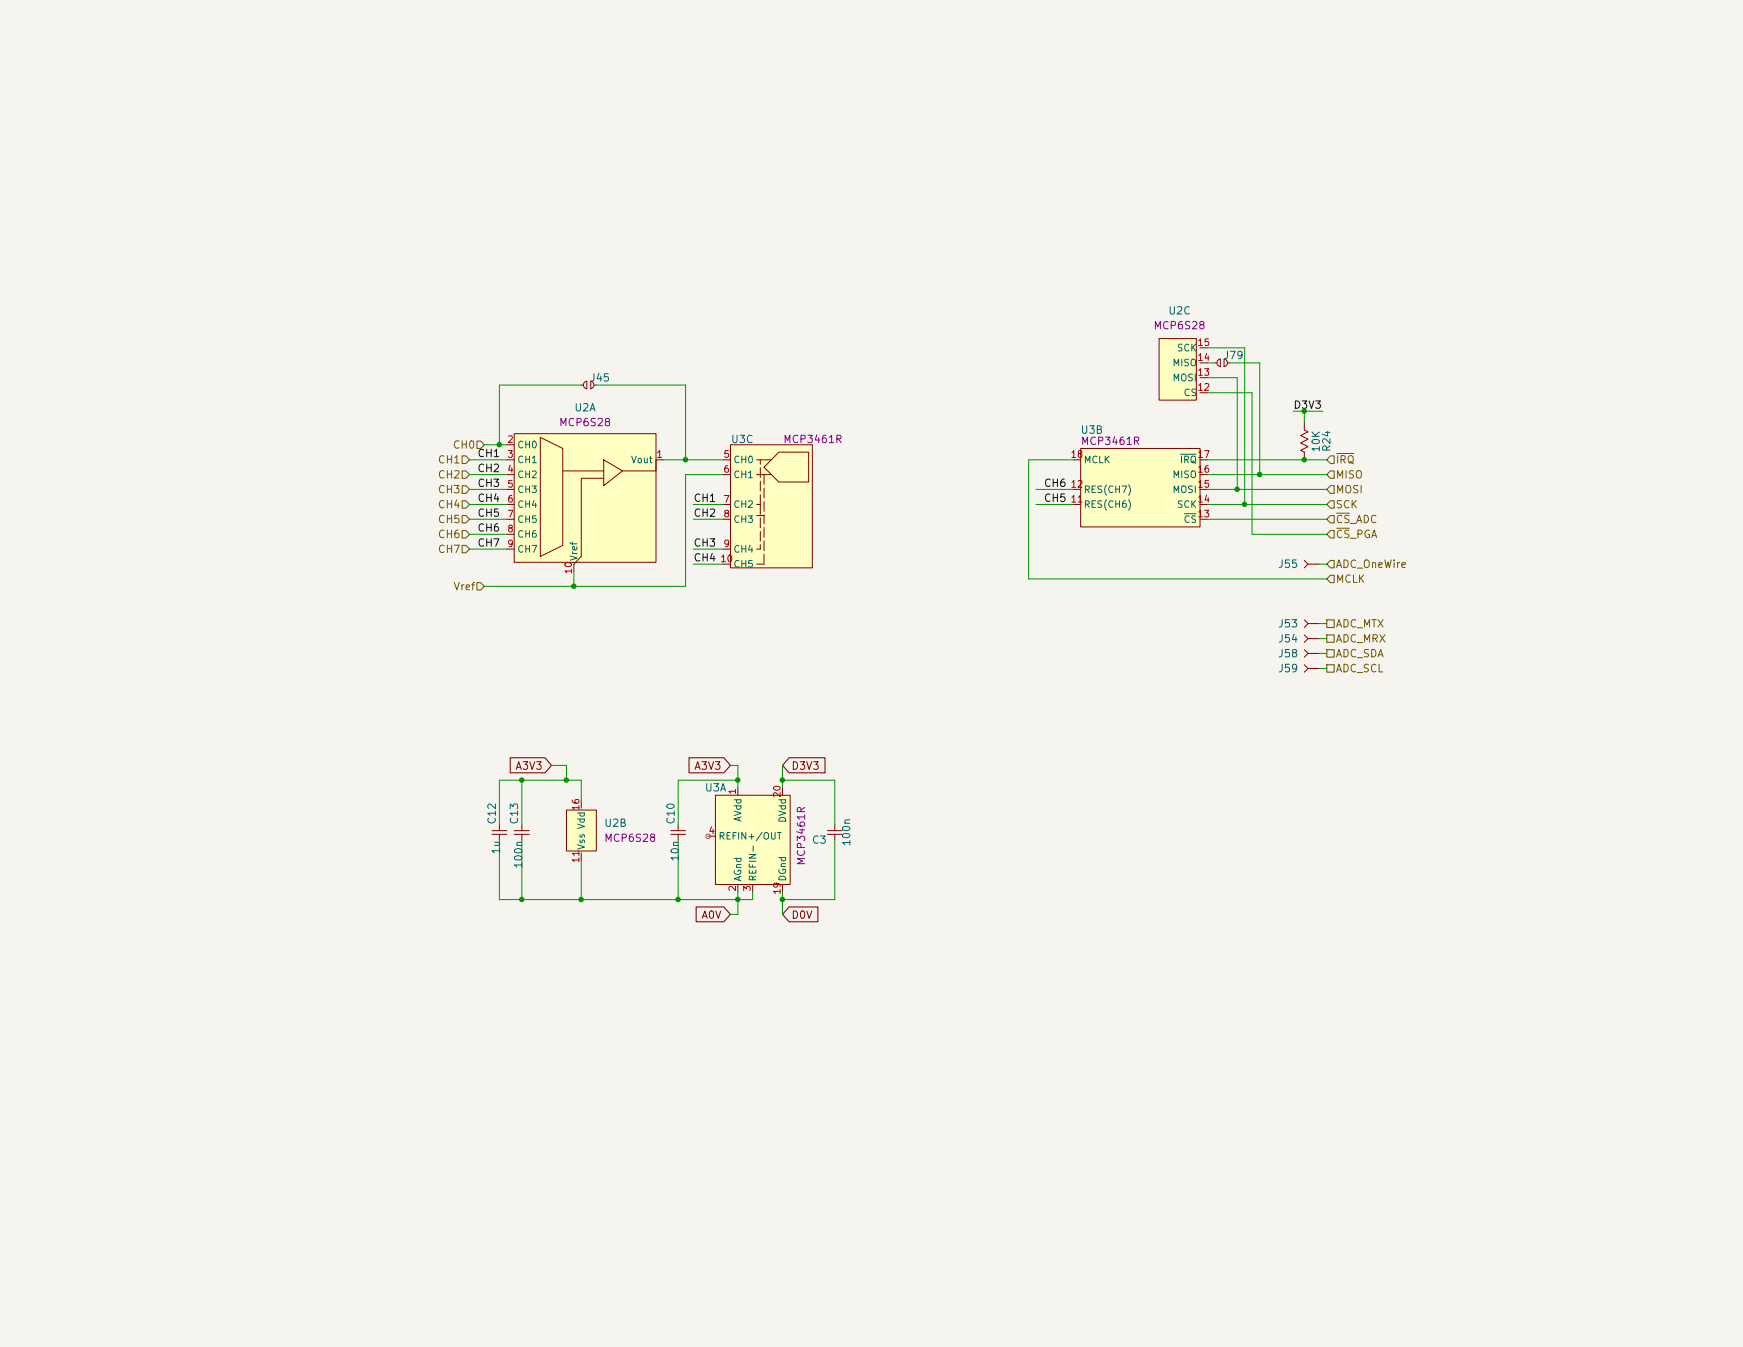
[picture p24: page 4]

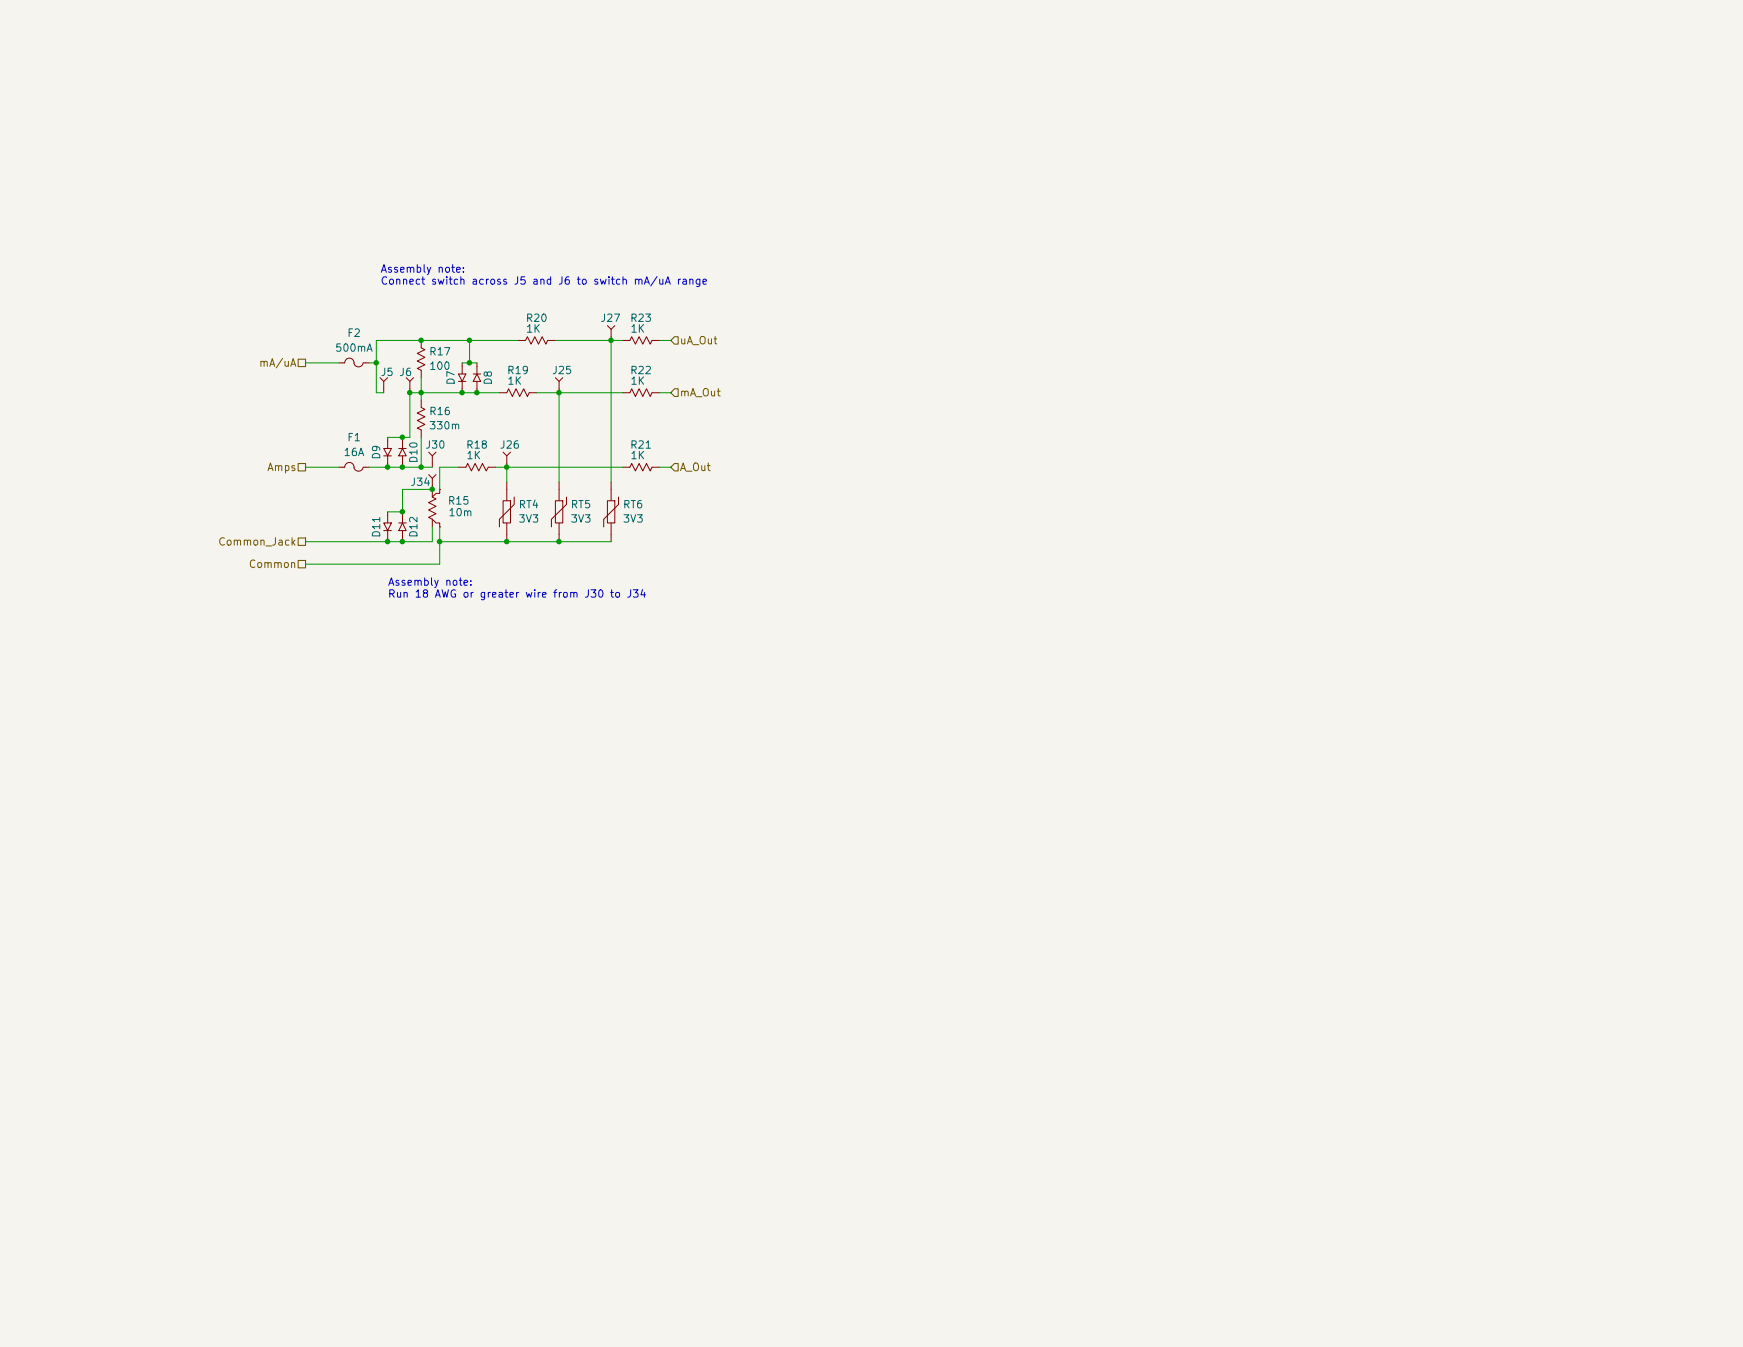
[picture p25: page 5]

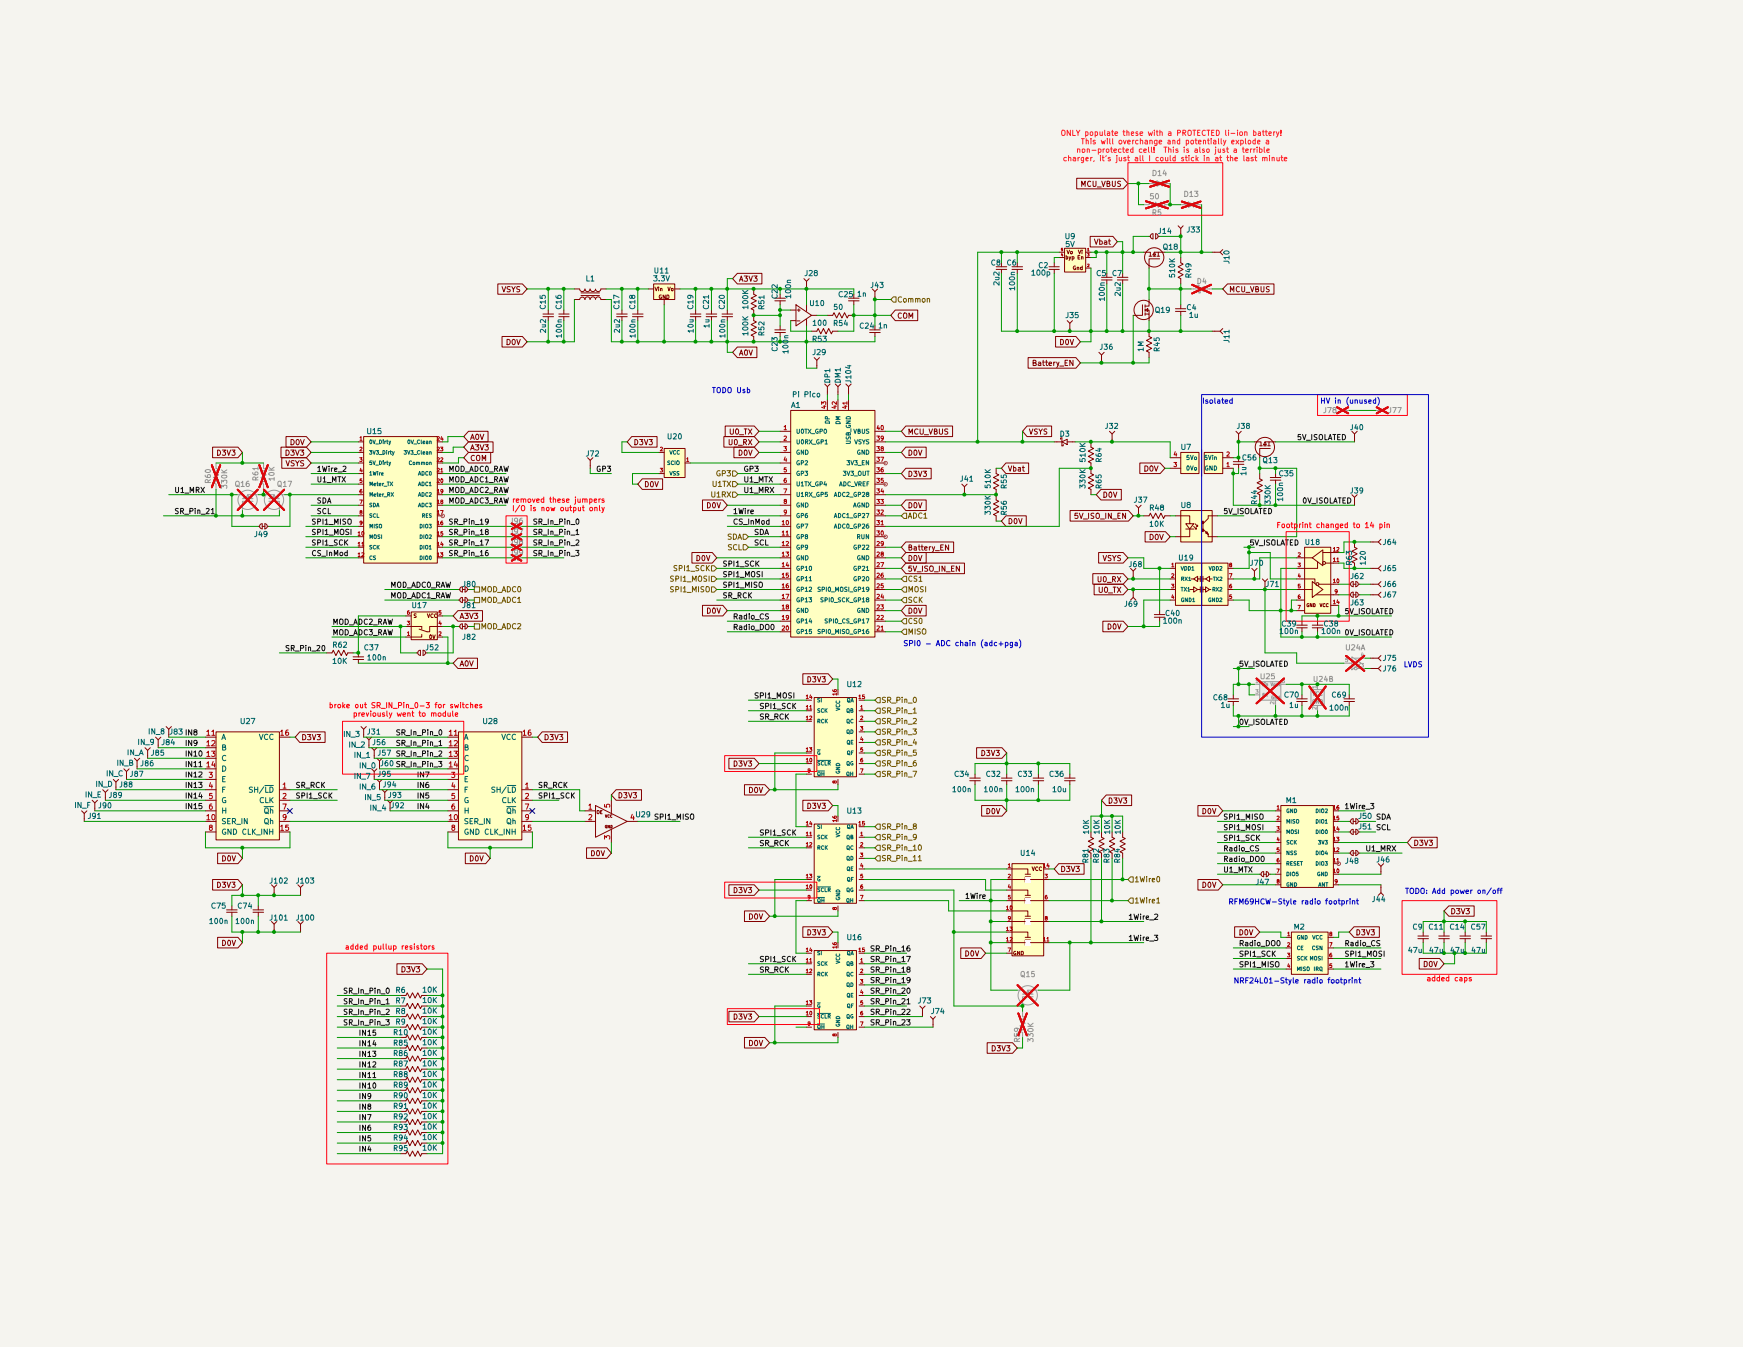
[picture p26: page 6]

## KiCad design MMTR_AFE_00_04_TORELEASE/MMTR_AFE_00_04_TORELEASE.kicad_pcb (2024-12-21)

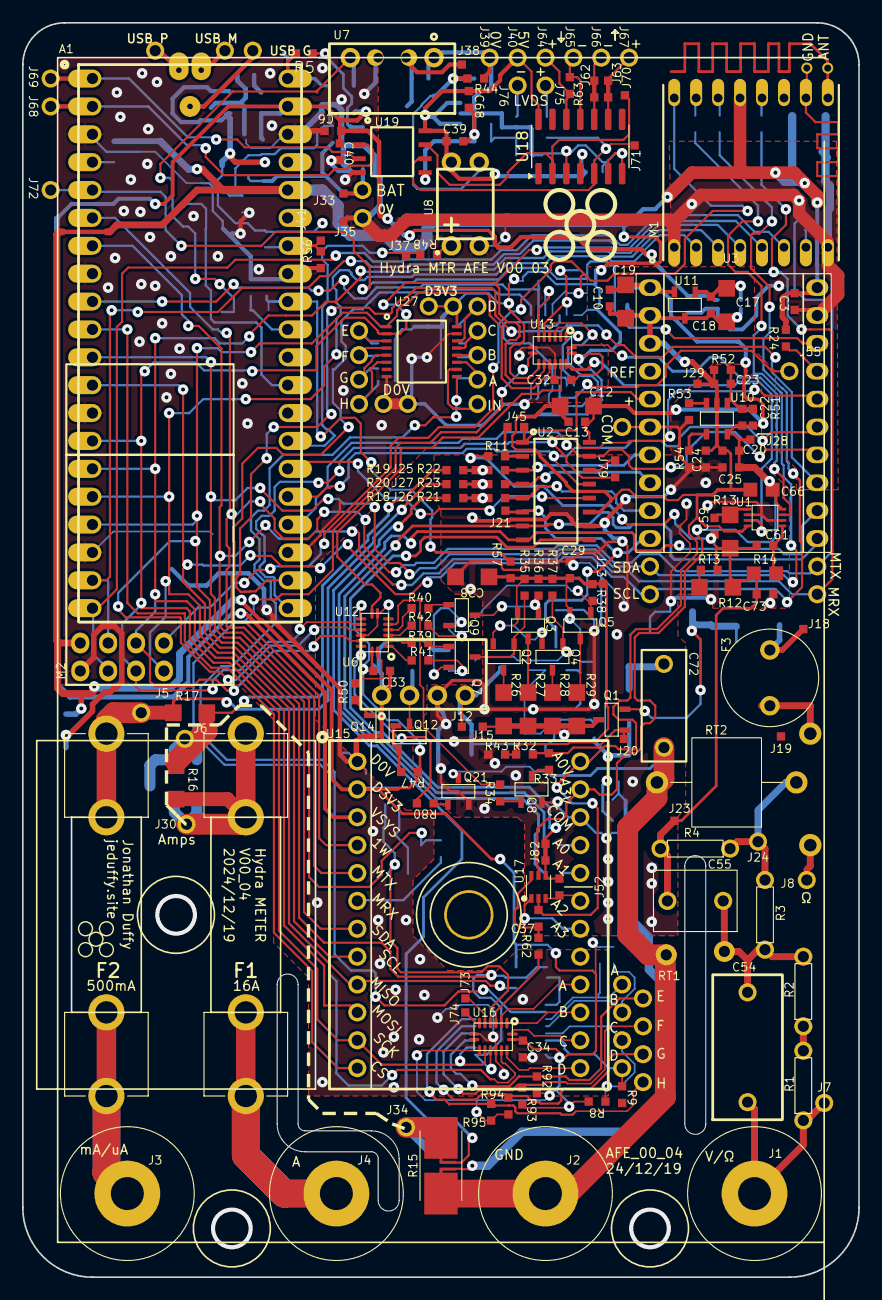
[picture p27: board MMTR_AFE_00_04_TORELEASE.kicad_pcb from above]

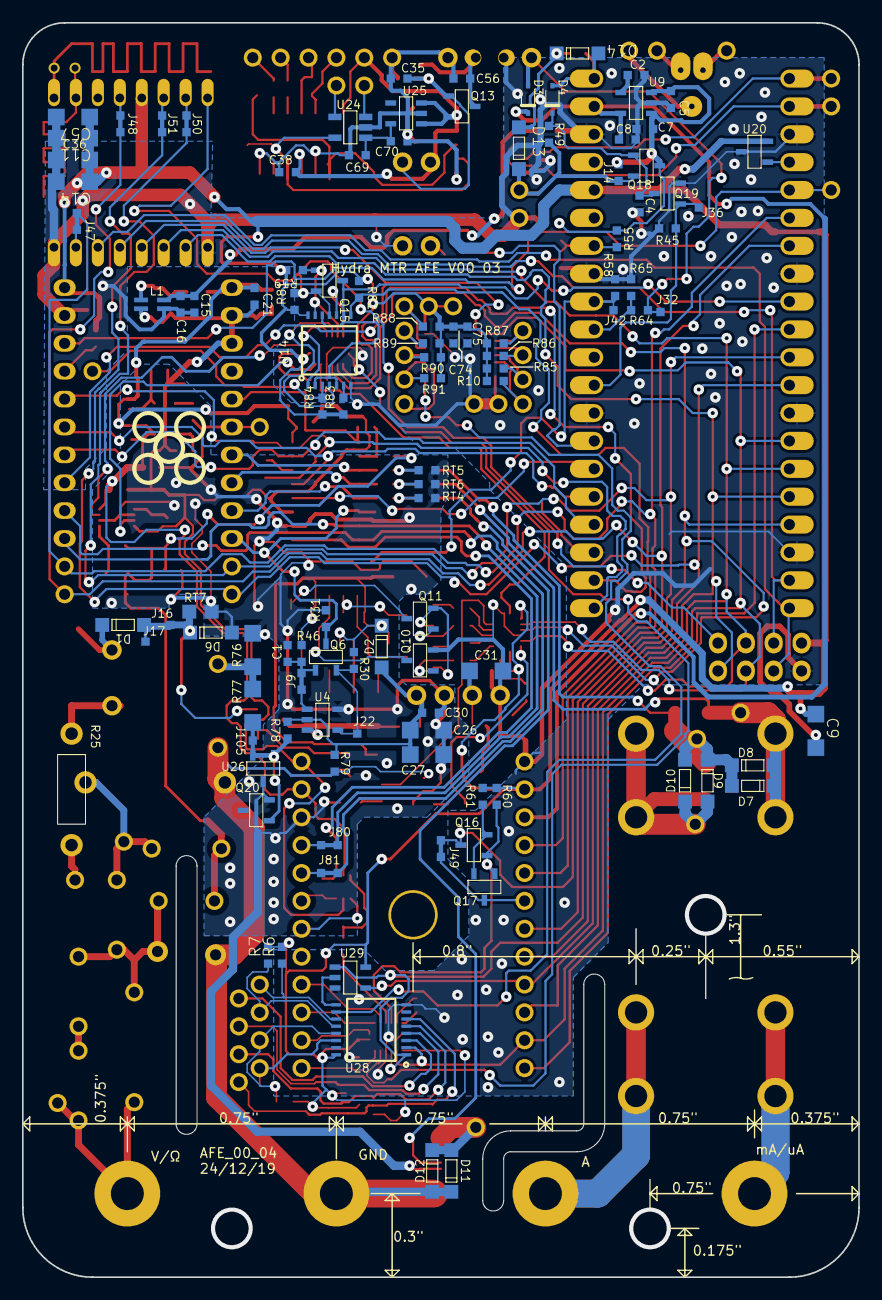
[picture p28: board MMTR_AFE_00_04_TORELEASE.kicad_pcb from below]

Board: 2 copper layers, 76.2 x 114.3 mm, 312 parts (109 on the bottom side), 183 nets.

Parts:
A1: Pi Pico; Pi_Pico_WUSB
C1: 10p; Cap_SMD_0603
C2: 100p; Cap_SMD_0603
C3, C5, C6, C13, C16, C18, C20, C22, C23, C29, C30, C32, C33, C34, C35, C37, C38, C39, C40, C69, C74, C75: 100n; Cap_SMD_0603
C4, C21, C56, C68, C70: 1u; Cap_SMD_0603
C7, C8, C15: 2u2; Cap_SMD_0603
C9, C11, C14, C57: 47u; Cap_SMD_1206
C10: 10n; Cap_SMD_0603
C12, C27, C28: 1u; Cap_SMD_1206
C17: 2u2; Cap_SMD_1206
C19, C26, C31, C36: 10u; Cap_SMD_1206
C24, C25: 1n; Cap_SMD_0603
C54: 1.5n; Cap_TH_Film_0.4Spc
C55: 220p; Cap_TH_Film_0.2Spc
C59: 1.8n; Cap_SMD_0603
C61: 27n; Cap_SMD_0603
C66: 100n; Cap_SMD_0805
C72: 0.1u; Cap_TH_Film_0.3Spc
C73: 33p; Cap_SMD_0603
D1, D2, D6, D7, D8, D9, D10, D11, D12, D13, D14: 1N4007FL
D3, D4: CUS08F30,H3F
DM1: Header_Pin_01x01
DP1: Header_Pin_01x01
F1: 16A; FC-102_BRIGHT_TIN
F2: 500mA; FC-102_BRIGHT_TIN
F3: 63mA; 0034.6062
J1, J2, J3, J4: CT2914
J5, J6, J7, J8, J10, J11, J24, J30, J34, J39, J40, J43, J53, J54, J55, J58, J59, J64, J65, J66, J67, J68, J69, J72, J75, J76, J91, J100, J101, J102, J103, J104: Header_Pin_01x01
J9, J47, J48, J49, J50, J51, J62, J63, J80, J81, J82: NC; Jumper_0603
J12, J13, J15, J16, J17, J18, J19, J20, J21, J22, J23, J25, J26, J27, J28, J29, J32, J33, J35, J36, J37, J38, J41, J42, J70, J71, J73, J74, J105: Test_Pad_30x30mil
J14, J45, J52, J79: NO; Jumper_0603_NO
J31: IN_3; Header_Pin_01x01
J44, J46: MiniPin_25mil
J56: IN_2; Header_Pin_01x01
J57: IN_1; Header_Pin_01x01
J60: IN_0; Header_Pin_01x01
J83: IN_8; Header_Pin_01x01
J84: IN_9; Header_Pin_01x01
J85: IN_A; Header_Pin_01x01
J86: IN_B; Header_Pin_01x01
J87: IN_C; Header_Pin_01x01
J88: IN_D; Header_Pin_01x01
J89: IN_E; Header_Pin_01x01
J90: IN_F; Header_Pin_01x01
J92: IN_4; Header_Pin_01x01
J93: IN_5; Header_Pin_01x01
J94: IN_6; Header_Pin_01x01
J95: IN_7; Header_Pin_01x01
L1: 500mOhm; WCM 2012F2SF-361T03
M1: RFM69HCW
M2: NRF24L01
Q1, Q2, Q3, Q4, Q5, Q6, Q12, Q15, Q16, Q17, Q19, Q20: DMN65D8L-7
Q7, Q8, Q9, Q10, Q11, Q13, Q14, Q18, Q21: SOT23-3
R1, R2: 100K; Resistor_THT_Vert_0p2_1o4W
R3, R4: 400K; Resistor_THT_Vert_0p2_1o4W
R5, R54: 50; Resistor_0603
R6, R7, R8, R9, R10, R24, R34, R39, R40, R41, R42, R43, R48, R50, R61, R62, R79, R81, R82, R83, R84, R85, R86, R87, R88, R89, R90, R91, R92, R93, R94, R95: 10K; Resistor_0603
R11, R18, R19, R20, R21, R22, R23, R31, R80: 1K; Resistor_0603
R12: 9M1; Resistor_1206
R13, R28: 100K; Resistor_1206
R14: 6K8; Resistor_0805
R15: 10m; Resistor_2512_4Pin
R16: 330m; Resistor_1206
R17: 100; Resistor_1206
R25: 1K; Resistor_1W_Thru_Wide
R26: 510; Resistor_1206
R27: 10K; Resistor_1206
R29: 1M; Resistor_1206
R30: 3K3; Resistor_0603
R32, R33, R58: 33K; Resistor_0603
R35, R36, R37, R38, R47, R51, R52, R57: 100K; Resistor_0603
R44, R46, R56, R59, R60, R65: 330K; Resistor_0603
R45, R78: 1M; Resistor_0603
R49, R55, R64: 510K; Resistor_0603
R53: 100; Resistor_0603
R63: 120; Resistor_0603
R76: 510K; Resistor_1206
R77: 220K; Resistor_1206
RT1: 230 VRMS; B72205S0231K311
RT2: 75 VRMS; 2045-07-BLF
RT3: 3.3V; MOV_0603
RT4, RT5, RT6: 3V3; MOV_0603
RT7: 18V; MOV_0805
U1: NL7WB66
U2: SOIC-16
U3: 20_Pin_Breakout_0p6_Wd
U4: SOT23-5_LMC7101BYM5-TR
U6: B0309S-1WR3
U7: RFM-0505S
U8: LTV-816
U9: 5V; SOT23-5
U10: SC-74A_LMR312
U11: 3.3V; SOT23-3
U12, U13, U16: 74HC595BQ,115; 16-DHVQFN_74HC595BQ
U14: TC7MBL3126CFT; TSSOP-14_TC7MBL3126CFT
U15: Mmtr_Input_Module
U17: PI5A3157CEX; SC-70_PI5A3157CEX
U18: SP491EEN; SOIC-14_3.9x8.7mm_P1.27mm
U19: STISO621TR; SOIC-8_STISO621TR
U20: 8kbit; SOT23-3
U24: DSLVDS1001DBVR; SC-74A_DSLVDS1001DBVR
U25: 3.3V; SOT23-5
U26: 7Vf 12Vr; SOT23-3
U27, U28: SN74HCS165PWR; TSSOP-16
U29: 74LVC1G126W5-7; SC-74A

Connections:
5V_ISO_IN_EN: A1.27 (GP21), J37.1, R48.2
/Amp_AFE/Amps: F1.1, J4.1
/Amp_AFE/Common_Jack: C72.2, D11.2 (K), D12.1 (A), J2.1, R15.1, RT1.2, RT2.2
/Amp_AFE/mA/uA: F2.1, J3.1
/MCU/0V_ISOLATED: C35.2, C38.2, C39.2, C56.2, C68.2, C69.2, C70.2, J39.1, R44.2, U7.1 (GND), U18.3 (RE), U18.6 (GND), U18.7 (GND), U19.5 (GND2), U24.2 (GND), U25.2 (GND)
/MCU/1Wire: A1.9 (GP6), Q15.3 (D), U14.2 (A1), U14.5 (A2), U14.9 (A3), U14.12 (A4)
/MCU/1Wire0: J55.1, R84.2, U14.3 (B1)
/MCU/1Wire1: R83.2, U14.6 (B2)
/MCU/1Wire_2: R82.2, U14.8 (B3), U15.4 (1Wire)
/MCU/1Wire_3: M1.16 (DIO2), M2.5 (IRQ), Q15.2 (S), R81.2, U14.11 (B4)
/MCU/5V_ISOLATED: C38.1, C39.1, C68.1, J40.1, Q13.2 (S), U8.4 (C), U18.4 (DE), U18.14 (VCC), U19.8 (VDD2), U25.1 (VIN), U25.3 (EN)
/MCU/ADC1: A1.32 (ADC1_GP27), J42.1, R57.1, R58.2
/MCU/CS0: A1.22 (SPI0_CS_GP17), U3.13 (~CS)
/MCU/CS1: A1.26 (GP20), U2.12 (CS)
/MCU/CS_InMod: A1.10 (GP7), U15.12 (CS)
/MCU/GP3: A1.5 (GP3), J72.1, U3.18 (MCLK)
/MCU/IN4: J92.1, R95.1, U28.6 (H)
/MCU/IN5: J93.1, R94.1, U28.5 (G)
/MCU/IN6: J94.1, R93.1, U28.4 (F)
/MCU/IN7: J95.1, R92.1, U28.3 (E)
/MCU/IN8: J83.1, R91.1, U27.11 (A)
/MCU/IN9: J84.1, R90.1, U27.12 (B)
/MCU/IN10: J85.1, R89.1, U27.13 (C)
/MCU/IN11: J86.1, R88.1, U27.14 (D)
/MCU/IN12: J87.1, R87.1, U27.3 (E)
/MCU/IN13: J88.1, R86.1, U27.4 (F)
/MCU/IN14: J89.1, R85.1, U27.5 (G)
/MCU/IN15: J90.1, R10.1, U27.6 (H)
/MCU/MISO: A1.21 (SPI0_MISO_GP16), J79.2, U3.16 (MISO)
/MCU/MOD_ADC0_RAW: J80.1, U15.21 (ADC0)
/MCU/MOD_ADC1_RAW: J81.1, U15.20 (ADC1)
/MCU/MOD_ADC2_RAW: J52.1, U15.19 (ADC2), U17.3 (B0)
/MCU/MOD_ADC3_RAW: U15.18 (ADC3), U17.1 (B1)
/MCU/MOSI: A1.25 (SPI0_MOSI_GP19), U2.13 (MOSI), U3.15 (MOSI)
/MCU/Radio_CS: A1.19 (GP14), M1.5 (NSS), M2.7 (CSN)
/MCU/Radio_DO0: A1.20 (GP15), M1.6 (RESET), M2.2 (CE)
/MCU/SCK: A1.24 (SPI0_SCK_GP18), U2.15 (SCK), U3.14 (SCK)
/MCU/SCL: A1.12 (GP9), J51.2, J59.1, U15.8 (SCL)
/MCU/SDA: A1.11 (GP8), J50.2, J58.1, U15.7 (SDA)
/MCU/SPI1_MISO: A1.16 (GP12), M1.2 (MISO), M2.4 (MISO), U15.9 (MISO), U29.4 (Y)
/MCU/SPI1_MOSI: A1.15 (GP11), M1.3 (MOSI), M2.6 (MOSI), U12.14 (SI), U15.10 (MOSI)
/MCU/SPI1_SCK: A1.14 (GP10), M1.4 (SCK), M2.3 (SCK), U12.11 (SCK), U13.11 (SCK), U15.11 (SCK), U16.11 (SCK), U27.2 (CLK), U28.2 (CLK)
/MCU/SR_In_Pin_0: J31.1, R6.1, U28.11 (A)
/MCU/SR_In_Pin_1: J56.1, R7.1, U28.12 (B)
/MCU/SR_In_Pin_2: J57.1, R8.1, U28.13 (C)
/MCU/SR_In_Pin_3: J60.1, R9.1, U28.14 (D)
/MCU/SR_Pin_0: R80.2, U12.15 (QA)
/MCU/SR_Pin_1: R50.2, U12.1 (QB)
/MCU/SR_Pin_2: R41.1, U12.2 (QC)
/MCU/SR_Pin_3: R39.1, U12.3 (QD)
/MCU/SR_Pin_4: R42.1, U12.4 (QE)
/MCU/SR_Pin_5: R40.1, U12.5 (QF)
/MCU/SR_Pin_6: R34.1, U12.6 (QG)
/MCU/SR_Pin_8: U1.3 (OE2), U13.15 (QA)
/MCU/SR_Pin_9: U1.7 (OE1), U13.1 (QB)
/MCU/SR_Pin_16: U15.13 (DIO0), U16.15 (QA)
/MCU/SR_Pin_17: U15.14 (DIO1), U16.1 (QB)
/MCU/SR_Pin_18: U15.15 (DIO2), U16.2 (QC)
/MCU/SR_Pin_19: U15.16 (DIO3), U16.3 (QD)
/MCU/SR_Pin_20: R62.2, U16.4 (QE)
/MCU/SR_Pin_21: Q16.1 (G), Q17.1 (G), R60.2, U16.5 (QF)
/MCU/SR_Pin_22: J73.1, U16.6 (QG)
/MCU/SR_Pin_23: J74.1, U16.7 (QH)
/MCU/SR_RCK: A1.17 (GP13), U12.12 (RCK), U13.12 (RCK), U16.12 (RCK), U27.1 (SH/~LD), U28.1 (SH/~LD), U29.1 (OE)
/MCU/U1_MRX: A1.7 (U1RX_GP5), J48.2, J49.1, J54.1, Q16.3 (D)
/MCU/U1_MTX: A1.6 (U1TX_GP4), J47.1, J53.1, U15.5 (Meter_TX)
/Ohm_AFE/9V5_Ohms: C26.1, C27.1, C30.1, D2.1 (A), J12.1, R78.1, R79.1, U4.2 (V+), U6.4 (9V)
/Ohm_AFE/Vpin: C54.1, J1.1, J7.1, R1.1
/PGA_ADC/CH0: J45.1, R11.2, U2.2 (CH0)
/PGA_ADC/CH1: R22.2, U2.3 (CH1), U3.7 (CH2)
/PGA_ADC/CH2: R23.2, U2.4 (CH2), U3.8 (CH3)
/PGA_ADC/CH3: R21.2, U2.5 (CH3), U3.9 (CH4)
/PGA_ADC/CH4: J21.1, Q6.3 (D), R31.1, U2.6 (CH4), U3.10 (CH5)
/PGA_ADC/CH5: J80.2, U2.7 (CH5), U3.11 (RES(CH6))
/PGA_ADC/CH6: J81.2, U2.8 (CH6), U3.12 (RES(CH7))
/PGA_ADC/CH7: J82.2, U2.9 (CH7)
/PGA_ADC/~IRQ: R24.2, U3.17 (~IRQ)
A0V: C10.2, C12.2, C13.2, C17.2, C18.2, C19.2, C20.2, C21.2, C23.2, C24.2, C37.2, C66.2, J29.1, L1.3, R52.1, U1.4 (GND), U2.11 (Vss), U3.2 (AGnd), U3.3 (REFIN-), U10.2 (V-), U11.3 (GND), U15.24 (0V_Clean), U17.2 (GND)
A3V3: C10.1, C12.1, C13.1, C19.1, C20.1, C21.1, C22.1, C25.1, C66.1, J28.1, R51.2, U1.8 (VCC), U2.16 (Vdd), U3.1 (AVdd), U10.5 (V+), U11.2 (Vout), U15.23 (3V3_Clean), U17.5 (VDD)
Battery_EN: A1.29 (GP22), J36.1, Q19.1 (G), R45.1
COM: C1.2, C24.1, C25.2, C26.2, C27.2, C28.2, C29.2, C30.2, C73.2, D6.1 (A), J43.1, Q8.2 (E), Q20.2 (S), Q21.2 (E), R12.2, R15.3, R31.2, R43.1, R53.2, R54.2, R76.2, RT3.2, RT4.2, RT5.2, RT6.2, RT7.2, U1.2 (COM1), U1.6 (COM2), U2.10 (Vref), U3.6 (CH1), U4.5 (V-), U6.3 (0V), U15.22 (Common), U26.3 (GND)
D0V: A1.3 (GND), A1.8 (GND), A1.13 (GND), A1.18 (GND), A1.23 (GND), A1.28 (GND), A1.33 (AGND), A1.38 (GND), C2.2, C3.2, C4.2, C5.2, C6.2, C7.2, C8.2, C9.2, C11.2, C14.2, C15.2, C16.2, C31.2, C32.2, C33.2, C34.2, C36.2, C40.2, C57.2, C74.2, C75.2, J11.1, J35.1, J100.1, J101.1, L1.4, M1.1 (GND), M1.8 (GND), M2.1 (GND), Q7.2 (E), Q9.2 (E), Q10.2 (E), Q11.2 (E), Q14.2 (E), Q19.2 (S), R45.2, R56.1, R58.1, R65.1, U3.19 (DGnd), U6.1 (GND), U7.3 (0Vo), U8.2 (K), U9.2 (GND), U12.8 (GND), U12.13 (~G), U13.8 (GND), U13.13 (~G), U14.7 (GND), U15.1 (0V_Dirty), U16.8 (GND), U16.13 (~G), U19.4 (GND1), U20.3 (VSS), U27.8 (GND), U27.15 (CLK_INH), U28.8 (GND), U28.15 (CLK_INH), U29.3 (GND)
D3V3: A1.36 (3V3_OUT), C3.1, C9.1, C11.1, C14.1, C32.1, C33.1, C34.1, C36.1, C57.1, C74.1, C75.1, J102.1, J103.1, M1.13 (3V3), M2.8 (VCC), Q12.2 (S), R6.2, R7.2, R8.2, R9.2, R10.2, R24.1, R47.1, R59.2, R60.1, R61.1, R81.1, R82.1, R83.1, R84.1, R85.2, R86.2, R87.2, R88.2, R89.2, R90.2, R91.2, R92.2, R93.2, R94.2, R95.2, U3.20 (DVdd), U12.10 (~SCLR), U12.16 (VCC), U13.10 (~SCLR), U13.16 (VCC), U14.14 (V+), U15.2 (3V3_Dirty), U16.10 (~SCLR), U16.16 (VCC), U20.2 (VCC), U27.16 (VCC), U28.16 (VCC), U29.5 (Vcc)
MCU_VBUS: A1.40 (VBUS), D4.1 (A), D14.1 (A), R5.1
unnamed: A1.31 (ADC0_GP26), R64.1, R65.2
unnamed: A1.34 (ADC2_GP28), J41.1, R55.1, R56.2
unnamed: A1.42 (DM), DM1.1
unnamed: A1.43 (DP), DP1.1
unnamed: A1.4 (GP2), U20.1 (SCIO)
unnamed: A1.41 (USB_GND), J104.1
unnamed: C54.2, C55.1, R2.2, R3.1, RT1.1
unnamed: C55.2, C59.1, C61.1, C73.1, J23.1, R4.2, R11.1, R12.1, R13.1, R14.1, RT3.1
unnamed: C72.1, R76.1, R77.2
unnamed: D1.1 (A), D6.2 (K), J16.1, J17.1, Q1.2 (S), RT7.1
unnamed: D1.2 (K), F3.2, J18.1
unnamed: C28.1, C29.1, D2.2 (K), J13.1, Q2.2 (S), Q3.2 (S), Q4.2 (S), Q5.2 (S), R30.1, R32.1, R35.1, R36.1, R37.1, R38.1, R43.2, R46.1, R57.2
unnamed: D3.1 (A), J32.1, R64.2, U7.4 (5Vo)
unnamed: C4.1, D4.2 (K), Q18.1 (G), Q19.3 (D), R49.1
unnamed: D7.1 (A), D8.2 (K), F2.2, J5.1, R17.1, R20.1
unnamed: D9.2 (K), D10.1 (A), F1.2, J30.1, R16.2
unnamed: D7.2 (K), D8.1 (A), D9.1 (A), D10.2 (K), J6.1, R16.1, R17.2, R19.1
unnamed: D11.1 (A), D12.2 (K), J34.1, R15.2
unnamed: D13.1 (A), D14.2 (K), R5.2
unnamed: D13.2 (K), J10.1, J14.2, J33.1, Q18.2 (S), R49.2
unnamed: F3.1, J19.1, R25.2
unnamed: J8.1, R25.1
unnamed: J24.1, R3.2, R4.1, RT2.1
unnamed: J25.1, R19.2, R22.1, RT5.1
unnamed: J26.1, R18.2, R21.1, RT4.1
unnamed: J27.1, R20.2, R23.1, RT6.1
unnamed: J46.1, M1.10 (GND)
unnamed: J62.2, J66.1
unnamed: J63.2, J67.1
unnamed: J44.1, M1.9 (ANT)
unnamed: J51.1, M1.14 (DIO0)
unnamed: J50.1, M1.15 (DIO1)
unnamed: J48.1, M1.12 (DIO4)
unnamed: J47.2, M1.7 (DIO5)
unnamed: J15.1, Q1.3 (D), R26.2, R27.2, R28.2, R29.2, U4.3 (IN+)
unnamed: J20.1, Q1.1 (G), R32.2, R33.1
unnamed: Q2.3 (D), R26.1
unnamed: Q2.1 (G), Q7.3 (C), R35.2
unnamed: Q3.3 (D), R27.1
unnamed: Q3.1 (G), Q9.3 (C), R36.2
unnamed: Q4.3 (D), R28.1
unnamed: Q5.3 (D), R29.1
unnamed: C1.1, J9.2, Q6.1 (G), R46.2
unnamed: J22.1, Q6.2 (S), R30.2, U4.4 (IN-)
unnamed: Q7.1 (B), R39.2
unnamed: Q8.1 (B), R34.2
unnamed: Q8.3 (C), R33.2
unnamed: Q9.1 (B), R40.2
unnamed: Q10.1 (B), R41.2
unnamed: Q4.1 (G), Q10.3 (C), R37.2
unnamed: Q11.1 (B), R42.2
unnamed: Q5.1 (G), Q11.3 (C), R38.2
unnamed: C31.1, Q12.3 (D), U6.2 (3V3)
unnamed: Q12.1 (G), Q14.3 (C), R47.2
unnamed: C56.1, J38.1, Q13.3 (D), U7.2 (5Vin)
unnamed: C35.1, Q13.1 (G), R44.1, U8.3 (E)
unnamed: Q14.1 (B), R50.1
unnamed: Q15.1 (G), R59.1, U13.6 (QG), U14.13 (4OE)
unnamed: Q16.2 (S), Q17.2 (S), R61.2
unnamed: J49.2, Q17.3 (D), U15.6 (Meter_RX)
unnamed: J105.1, Q20.1 (G), R77.1, R78.2, U26.1 (IO1), U26.2 (IO2)
unnamed: Q21.1 (B), R80.1
unnamed: Q21.3 (C), R79.2
unnamed: R1.2, R2.1
unnamed: R15.4, R18.1
unnamed: C59.2, R13.2, U1.1 (NO1)
unnamed: C61.2, R14.2, U1.5 (NO2)
unnamed: J45.2, U2.1 (Vout), U3.5 (CH0)
unnamed: J79.1, U2.14 (MISO)
unnamed: J9.1, U4.1 (OUT)
unnamed: R48.1, U8.1 (A)
unnamed: C2.1, U9.4 (BYP)
unnamed: C22.2, C23.1, R51.1, R52.2, U10.1 (IN+)
unnamed: R53.1, U10.3 (IN-)
unnamed: R54.1, U10.4 (OUT)
unnamed: C17.1, C18.1, L1.2, U11.1 (Vin)
unnamed: U12.9 (~QH), U13.14 (SI)
unnamed: U13.4 (QE), U14.1 (OE1)
unnamed: U13.5 (QF), U14.4 (2OE)
unnamed: U13.7 (QH), U14.10 (3OE)
unnamed: U13.9 (~QH), U16.14 (SI)
unnamed: J52.2, J82.1, U17.4 (A)
unnamed: C37.1, R62.1, U17.6 (S)
unnamed: J64.1, R63.1, U18.12 (A)
unnamed: J65.1, R63.2, U18.11 (B)
unnamed: J71.1, U18.5 (D), U19.6 (RX2), U24.5 (TTL_IN)
unnamed: J70.1, U18.2 (R), U19.7 (TX2)
unnamed: J63.1, U18.9 (Y)
unnamed: J62.1, U18.10 (Z)
unnamed: J75.1, U24.4 (OUT+)
unnamed: J76.1, U24.3 (OUT-)
unnamed: C69.1, C70.1, U24.1 (VDD), U25.5 (VOUT)
unnamed: U27.9 (Qh), U28.10 (SER_IN)
unnamed: J91.1, U27.10 (SER_IN)
unnamed: U28.9 (Qh), U29.2 (A)
U0_RX: A1.2 (U0RX_GP1), J68.1, U19.2 (RX1)
U0_TX: A1.1 (U0TX_GP0), J69.1, U19.3 (TX1)
VSYS: A1.39 (VSYS), C6.1, C8.1, C15.1, C16.1, C40.1, D3.2 (K), L1.1, U9.5 (VOUT), U15.3 (5V_Dirty), U19.1 (VDD1)
Vbat: C5.1, C7.1, J14.1, Q18.3 (D), R55.2, U9.1 (Vin), U9.3 (EN)

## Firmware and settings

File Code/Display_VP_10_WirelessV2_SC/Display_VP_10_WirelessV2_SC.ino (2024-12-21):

#include "ST7565.h"
#include <nrf24.h>
#include <SPI.h>

// the LCD backlight is connected up to a pin so you can turn it on & off
#define BACKLIGHT_LED 22

// pin 9 - Serial data out (SID)
// pin 8 - Serial clock out (SCLK)
// pin 7 - Data/Command select (RS or A0)
// pin 6 - LCD reset (RST)
// pin 5 - LCD chip select (CS)
//15->I
//14->II
//13->L
//12->R
#define PIN_I 9 //9 - 15
#define PIN_II 8 //8 - 14
#define PIN_L 7 //7 - 13
#define PIN_R 6 //6 - 12

#define SPI1_SCK 10
#define SPI1_MOSI 11
#define SPI1_MISO 12
#define RADIO_CS 14
#define RADIO_DO0 15

ST7565 glcd(19, 18, 16, 20, 17);
nrf24 nrfRadio(RADIO_DO0,RADIO_CS);//ce,cs

#define LOGO16_GLCD_HEIGHT 16 
#define LOGO16_GLCD_WIDTH  16 

// a bitmap of a 16x16 quincunx
const static unsigned char __attribute__ ((progmem)) logo16_glcd_bmp[]={
0x1C, 0x22, 0x41, 0x41, 0xC1, 0x62, 0x3C, 0x10, 0x10, 0x3C, 0x62, 0xC1, 0x41, 0x41, 0x22, 0x1C, 
0x38, 0x44, 0x82, 0x82, 0x83, 0x46, 0x3C, 0x08, 0x08, 0x3C, 0x46, 0x83, 0x82, 0x82, 0x44, 0x38,};

#define STATE_STRING_LENGTH 16 //max length of the state string
char stateString[STATE_STRING_LENGTH+1];//+1 for guaranteed null term
int stateStreamIndex = 0;

#define MAX_DATA_STREAMS 16
#define MAX_DATA_STREAM_ID_LENGTH 4
#define MAX_DATA_STREAM_LABEL_LENGTH 20
#define MAX_DATA_STREAM_UNIT_LENGTH 3
#define MAX_DATA_STREAM_STR_LENGTH 16

int64_t dataStreamLastUpdate[MAX_DATA_STREAMS];
char dataStreamIDs[MAX_DATA_STREAMS][MAX_DATA_STREAM_ID_LENGTH];//TODO add 1 length and force null term
char dataStreamLabels[MAX_DATA_STREAMS][MAX_DATA_STREAM_LABEL_LENGTH];
char dataStreamUnits[MAX_DATA_STREAMS][MAX_DATA_STREAM_UNIT_LENGTH];
double dataStreamValues[MAX_DATA_STREAMS];
char dataStreamStringVal[MAX_DATA_STREAMS][MAX_DATA_STREAM_STR_LENGTH];
bool dataStreamIsInfo[MAX_DATA_STREAMS];
bool dataStreamIsStringVal[MAX_DATA_STREAMS];
bool doDispDataStream[MAX_DATA_STREAMS];

typedef union {
	uint8_t byteAr[4];
	float flt;
} floatToBytes_t;

int matchDataStreamID(char* in){
  for(int i=0;i<MAX_DATA_STREAMS;i++){
    //Serial.print("Does <");Serial.print(dataStreamIDs[i]);
    //Serial.print("> match <");Serial.println(in);
    for(int j=0;j<MAX_DATA_STREAM_ID_LENGTH;j++){
      if(dataStreamIDs[i][j] == in[j]){
        //Serial.print(".");
        if(in[j] == '\0'){
          //Serial.print("Returning ");Serial.println(i);
          //if(j==0){
          //  return -1;
          //}
          return i;
        }
      }else{
        j=1000;
        break;//break out of inner loop (j) - labels don't match
      }
    }
  }
  return -1;
}

void easyEngFltPrint(char* strng,double val){
  double absv = abs(val);
  if(val >= 0){
    strng[0] = ' ';
    strng++;
  }
  if(absv < 0.99995e-5){
    sprintf(strng,"%1.4fu",val*1e6);
  }else if(absv < 0.99995e-4){
    sprintf(strng,"%1.3fu",val*1e6);
  }else if(absv < 0.99995e-3){
    sprintf(strng,"%1.2fu",val*1e6);
  }else if(absv < 0.99995e-2){
    sprintf(strng,"%1.4fm",val*1e3);
  }else if(absv < 0.99995e-1){
    sprintf(strng,"%1.3fm",val*1e3);
  }else if(absv < 0.5){
    sprintf(strng,"%3.2fm",val*1e3);
  }else if(absv < 0.99995e1){
    sprintf(strng,"%1.4f",val);
  }else if(absv < 0.99995e2){
    sprintf(strng,"%1.3f",val);
  }else if(absv < 0.99995e3){
    sprintf(strng,"%1.2f",val);
  }else if(absv < 0.99995e4){
    sprintf(strng,"%1.4fK",val/1e3);
  }else if(absv < 0.99995e5){
    sprintf(strng,"%1.3fK",val/1e3);
  }else if(absv < 0.99995e6){
    sprintf(strng,"%1.2fK",val/1e3);
  }else if(absv < 0.99995e7){
    sprintf(strng,"%1.4fM",val/1e6);
  }else if(absv < 0.99995e8){
    sprintf(strng,"%1.3fM",val/1e6);
  }else if(absv < 0.99995e9){
    sprintf(strng,"%1.2fM",val/1e6);
  }else if(absv < 0.99995e10){
    sprintf(strng,"%1.4fG",val/1e9);
  }else if(absv < 0.99995e11){
    sprintf(strng,"%1.3fG",val/1e9);
  }else if(absv < 0.99995e10){
    sprintf(strng,"%1.2fG",val/1e9);
  }
}

//engineering float print with separate prefix (pstrng = 'M' or 'K' or whatever)
//also puts leading space in >0
void easyEngFltPrintSepPx(char* dstrng,char* pstrng,double val){
  double absv = abs(val);
  if(val >= 0){
    dstrng[0] = ' ';
    dstrng++;
  }
  if(absv < 0.99995e-5){
    sprintf(dstrng,"%1.4f",val*1e6);
    pstrng[0] = 'u';
    pstrng[1] = '\0';
  }else if(absv < 0.99995e-4){
    sprintf(dstrng,"%1.3f",val*1e6);
    pstrng[0] = 'u';
    pstrng[1] = '\0';
  }else if(absv < 0.99995e-3){
    sprintf(dstrng,"%1.2f",val*1e6);
    pstrng[0] = 'u';
    pstrng[1] = '\0';
  }else if(absv < 0.99995e-2){
    sprintf(dstrng,"%1.4f",val*1e3);
    pstrng[0] = 'm';
    pstrng[1] = '\0';
  }else if(absv < 0.99995e-1){
    sprintf(dstrng,"%1.3f",val*1e3);
    pstrng[0] = 'm';
    pstrng[1] = '\0';
  }else if(absv < 0.5){
    sprintf(dstrng,"%1.2f",val*1e3);
    pstrng[0] = 'm';
    pstrng[1] = '\0';
  }else if(absv < 0.99995e1){
    sprintf(dstrng,"%1.4f",val);
    pstrng[0] = '\0';
  }else if(absv < 0.99995e2){
    sprintf(dstrng,"%1.3f",val);
    pstrng[0] = '\0';
  }else if(absv < 0.99995e3){
    sprintf(dstrng,"%1.2f",val);
    pstrng[0] = '\0';
  }else if(absv < 0.99995e4){
    sprintf(dstrng,"%1.4f",val/1e3);
    pstrng[0] = 'K';
    pstrng[1] = '\0';
  }else if(absv < 0.99995e5){
    sprintf(dstrng,"%1.3f",val/1e3);
    pstrng[0] = 'K';
    pstrng[1] = '\0';
  }else if(absv < 0.99995e6){
    sprintf(dstrng,"%1.2f",val/1e3);
    pstrng[0] = 'K';
    pstrng[1] = '\0';
  }else if(absv < 0.99995e7){
    sprintf(dstrng,"%1.4f",val/1e6);
    pstrng[0] = 'M';
    pstrng[1] = '\0';
  }else if(absv < 0.99995e8){
    sprintf(dstrng,"%1.3f",val/1e6);
    pstrng[0] = 'M';
    pstrng[1] = '\0';
  }else if(absv < 0.99995e9){
    sprintf(dstrng,"%1.2f",val/1e6);
    pstrng[0] = 'M';
    pstrng[1] = '\0';
  }else if(absv < 0.99995e10){
    sprintf(dstrng,"%1.4f",val/1e9);
    pstrng[0] = 'G';
    pstrng[1] = '\0';
  }else if(absv < 0.99995e11){
    sprintf(dstrng,"%1.3f",val/1e9);
    pstrng[0] = 'G';
    pstrng[1] = '\0';
  }else if(absv < 0.99995e12){
    sprintf(dstrng,"%1.2f",val/1e9);
    pstrng[0] = 'G';
    pstrng[1] = '\0';
  }
}

void parseRadio(uint8_t* buf){
  char streamID[3];
  int dataStreamIndex = -1;
  boolean dataStreamIsString = false;
  boolean failed = false;
  streamID[2] = '\0';
  streamID[0] = buf[0];
  streamID[1] = buf[1];
  Serial.print("RadMatch:");
  Serial.println(streamID);
  int index = matchDataStreamID(streamID);
  if(index>=0 && index <MAX_DATA_STREAMS){
    dataStreamIndex = index;
    if(dataStreamIsStringVal[index]){
      dataStreamIsString = true;
    }else{
      dataStreamIsString = false;
    }
  }else{
    failed = true;
  }
  if(failed){
    Serial.println("No match");
    return;
  }
  if(dataStreamIndex == stateStreamIndex){
    int strind = (buf[2]-'0')*3; //TODO need to tell when we're done, so we can end string
    if(strind + 4 >= STATE_STRING_LENGTH){
      return;//out of bounds, do nothing
    }
    stateString[strind] = buf[3];
    stateString[strind+1] = buf[4];
    stateString[strind+2] = buf[5];
    stateString[strind+3] = '\0';
  }else if(dataStreamIsString){
    //char streamStr[5];
    //streamStr[4] = '\0';
    //for(int i=0;i<4;i++){
    //  streamStr[i] = buf[i+2];
    //}
    //strncpy(&dataStreamStringVal[dataStreamIndex][0],streamStr,MAX_DATA_STREAM_STR_LENGTH);
    dataStreamStringVal[dataStreamIndex][0] = buf[2];
    dataStreamStringVal[dataStreamIndex][1] = buf[3];
    dataStreamStringVal[dataStreamIndex][2] = buf[4];
    dataStreamStringVal[dataStreamIndex][3] = buf[5];
    Serial.printf("Wrote str:%s\r\n",&dataStreamStringVal[dataStreamIndex][0]);
  }else{
    floatToBytes_t fltConv;
    fltConv.byteAr[0] = buf[2];
    fltConv.byteAr[1] = buf[3];
    fltConv.byteAr[2] = buf[4];
    fltConv.byteAr[3] = buf[5];
    dataStreamValues[dataStreamIndex] = (double)fltConv.flt;
    Serial.printf("Wrote val:%f\r\n",fltConv.flt);
  }
  dataStreamLastUpdate[dataStreamIndex] = millis();
}

void parseSerial(char in){ //TODO cleanup reuse of dataStreamIsString checks/calls
  static int64_t upper = 0;
  static double lower = 0;
  static int digitNum = 0;
  static boolean isBeforeDec = false;
  static boolean isBeforeNumber = false;
  static boolean isDone = false;
  static char streamID[MAX_DATA_STREAM_ID_LENGTH];
  static char streamStr[MAX_DATA_STREAM_STR_LENGTH+1];
  static int idI = 0;
  static boolean failed = false;
  static int dataStreamIndex = 0;
  static boolean dataStreamIndexSet = false;
  static boolean dataStreamIsString = false;
  static boolean isNegative = false;
  //Serial.print("<<");Serial.print(in);Serial.println(">>");
  if(in >= '0' && in <= '9'){
    if(!failed){
      if(isBeforeNumber){
        streamID[idI] = in;
        idI++;
        if(idI > MAX_DATA_STREAM_ID_LENGTH){
          idI = 0;
          failed = true;
        }
      }else if(dataStreamIsString){
        streamStr[digitNum] = in;
        digitNum++;
        if(digitNum >= MAX_DATA_STREAM_STR_LENGTH){
          failed = true;
          digitNum = 0;
        }
      }else{
        if(isBeforeDec){
          upper *= 10;
          upper += in-'0';
        }else{
          digitNum --;
          lower += (in-'0') * pow(10,digitNum);
        }
      }
    }
  }else if((in >= 'A' && in<'Z') || (in >= 'a' && in <= 'z')){
    if(!failed){
      if(isBeforeNumber){
          //Serial.print('>');Serial.print(in);
          streamID[idI] = in;
          idI++;
          if(idI > MAX_DATA_STREAM_ID_LENGTH){
            idI = 0;
            failed = true;
          }
      }else{
        if(dataStreamIsString){
          streamStr[digitNum] = in;
          digitNum++;
          if(digitNum >= MAX_DATA_STREAM_STR_LENGTH){
            failed = true;
            digitNum = 0;
          }
        }
      }
    }
  }else{
    switch(in){
    case '\r':
    case '\n':{
      if(!failed && dataStreamIndex >= 0){
        if(dataStreamIsString){
          streamStr[digitNum] = '\0';
          digitNum++;
          strncpy(&dataStreamStringVal[dataStreamIndex][0],streamStr,MAX_DATA_STREAM_STR_LENGTH);
        }else{
          dataStreamValues[dataStreamIndex] = ((double)upper + lower) * (isNegative?-1:1);
        }
        dataStreamLastUpdate[dataStreamIndex] = millis();
        Serial.print("Got value ");
        Serial.print(streamID);
        Serial.print(" : ");
        if(dataStreamIsString){
          Serial.println(dataStreamStringVal[dataStreamIndex]);
        }else{
          Serial.println(dataStreamValues[dataStreamIndex]);
        }
      }else{
        Serial.println("Failed, done");
      }
      idI = 0;
      isBeforeDec = true;
      isBeforeNumber=true;
      isDone = false;
      digitNum = 0;
      upper = 0;
      lower = 0;
      failed = false;
      idI = 0;
      dataStreamIndex = -1;
      dataStreamIndexSet = false;
      dataStreamIsString = false;
      isNegative = false;
      streamStr[MAX_DATA_STREAM_STR_LENGTH] = '\0';
    }
    break;
    case '.':
    if(dataStreamIsString){
      streamStr[digitNum] = in;
      digitNum++;
      if(digitNum >= MAX_DATA_STREAM_STR_LENGTH){
        failed = true;
        digitNum = 0;
      }
    }else{
      isBeforeDec = false;
    }
    //Serial.println("Decimal");
    break;
    case ',':
      if(dataStreamIsString){
        streamStr[digitNum] = in;
        digitNum++;
        if(digitNum >= MAX_DATA_STREAM_STR_LENGTH){
          failed = true;
          digitNum = 0;
        }
      }
    break;
    case '=':{
      isBeforeNumber = false;
      streamID[idI] = '\0';
      Serial.print("Matching<");
      Serial.print(idI);Serial.print('>');
      Serial.println(streamID);
      int index = matchDataStreamID(streamID);
      if(index>=0 && index <MAX_DATA_STREAMS){
        //Serial.print("Found data stream:");
        dataStreamIndex =index;
        if(dataStreamIsStringVal[index]){
          dataStreamIsString = true;
        }else{
          dataStreamIsString = false;
        }
        //Serial.println(index);
        dataStreamIndexSet = true;
      }else{
        //Serial.println("didn't find data stream :(");
        failed = true;
      }
    }
    break;
    case '\0':
    break;
    case '-':
      if(dataStreamIsString){
        streamStr[digitNum] = in;
        digitNum++;
        if(digitNum >= MAX_DATA_STREAM_STR_LENGTH){
          failed = true;
          digitNum = 0;
        }
      }else{
        isNegative = true;
      }
    break;
    //these are all explicitly allowed in string values, chars aren't by default
    //notable EXCEPTIONS, are '=' (used to separate ID from value), and control chars (\t, \r, \n,). '_' is reserved for unused
    case ':':
    case '{':
    case '}':
    case '<':
    case '>':
    case '\'':
    case '\"':
    case ')':
    case '(':
    case '#':
    case '@':
    case '!':
    case '$':
    case '%':
    case '^':
    case '&':
    case '*':
    case '[':
    case ']':
    case ';':
    case '?':
    case '+':
    case ' ':
      if(dataStreamIsString){
        streamStr[digitNum] = in;
        digitNum++;
        if(digitNum >= MAX_DATA_STREAM_STR_LENGTH){
          failed = true;
          digitNum = 0;
        }
      }
    break;
    default:
    break;
    }
  }
}
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
void loop(){
  static uint32_t lastHandShake=0;
  if(millis()-lastHandShake > 250){
    lastHandShake = millis();
    Serial1.println('H');
  }
  while(Serial1.available()){
    char ch = Serial1.read();
    parseSerial(ch);
  }
  if(nrfRadio.rxAvailable()) {
    uint8_t buf[8];
    nrfRadio.readPayload(buf,6);
    parseRadio(buf);
  }
  static uint32_t last = 0;
  if(millis()-last > 300){
    last = millis();
    Serial.println("postser");
    int numActiveStreams = 0;
    static int prevStreamNo = 0;
    int activeStreams[MAX_DATA_STREAMS];
    int numInfoStreams = 0;
    int infoStreams[MAX_DATA_STREAMS];
    Serial.print("StateStr:");
    for(int i=0;i<32;i++){
      if(stateString[i] != '\0'){
        Serial.print(stateString[i]);
      }else{
        break;
      }
    }
    Serial.println();
    for(int i=0;i<MAX_DATA_STREAMS;i++){
      if( ((millis()-dataStreamLastUpdate[i]) < (int64_t)350) &&  doDispDataStream[i]){
        if(dataStreamIsInfo[i]){
          infoStreams[numInfoStreams] = i;
          numInfoStreams++;
        }else{
          activeStreams[numActiveStreams]=i;
          numActiveStreams++;
        }
      }
    }
    Serial.println("streams counted");
    if(numActiveStreams != prevStreamNo){
      glcd.clear();
    }
    if(numActiveStreams == 0){
      Serial.print("no active streams");
      glcd.drawBigString_24(0,0,"No Streams",LCDWIDTH);
      glcd.drawBigString_24(0,3,"             ",LCDWIDTH);
      glcd.drawBigString_16(0,5,"HYDRA Meter",LCDWIDTH);
      glcd.drawString(0,7,"            ",LCDWIDTH);
    }else if(numActiveStreams == 1){
      Serial.println("1 active stream");
      int idx = activeStreams[0];
      char dstrng[16];
      char pstrng[16];
      Serial.print("idx:");Serial.println(idx);
      Serial.println("easyprint");
      easyEngFltPrintSepPx(dstrng,pstrng,dataStreamValues[idx]);
      Serial.println("draw big");
      Serial.print(dstrng);Serial.println(pstrng);
      int xe = 0;
      if(dataStreamIDs[idx][0] == 'R' && dataStreamIDs[idx][1] == '\0'){
        if(dataStreamValues[idx] < 0 || dataStreamValues[idx] >= 9999999.0){
          easyEngFltPrintSepPx(dstrng,pstrng,10000000);
          xe = glcd.drawBigString_48(0,2,dstrng,LCDWIDTH-1);
        }else{
          xe = glcd.drawBigString_48(0,2,dstrng,LCDWIDTH-1);
        }
      }else{
        xe = glcd.drawBigString_48(0,2,dstrng,LCDWIDTH-1);
      }
      if(pstrng[0] != '\0'){
        glcd.drawBigString_24(xe,4,pstrng,LCDWIDTH-1);
        //xe = xe + glcd.drawBigString(xe+2,4,dataStreamUnits[idx],LCDWIDTH-1);
      }
      Serial.print("Print units:");
      xe+=2;
      Serial.println(dataStreamUnits[idx]);
      glcd.drawBigString_16(xe,2,dataStreamUnits[idx],LCDWIDTH);
      Serial.println("P label");
      Serial.println(dataStreamLabels[idx]);
      glcd.drawBigString_8(0,0,dataStreamLabels[idx],LCDWIDTH);
      if(numInfoStreams > 0){
        //easyEngFltPrint(dstrng,dataStreamStringVal[infoStreams[0]]);
        xe = glcd.drawBigString_8(0,1,dataStreamLabels[infoStreams[0]],LCDWIDTH);
        Serial.printf("Infostr0:%s xe=%d",dataStreamLabels[infoStreams[0]],xe);
        if(dataStreamIsStringVal[infoStreams[0]]){
          xe += glcd.drawBigString_8(xe+2,1,dataStreamStringVal[infoStreams[0]],LCDWIDTH);
          Serial.printf(" = %s\n",dataStreamStringVal[infoStreams[0]]);
        }else{
          easyEngFltPrint(dstrng,dataStreamValues[infoStreams[0]]);
          xe += glcd.drawBigString_8(xe+2,1,dstrng,LCDWIDTH);
          Serial.printf(" = %s\n",dstrng);
        }
        xe += glcd.drawBigString_8(xe+2,1,dataStreamUnits[infoStreams[0]],LCDWIDTH);
      }
      Serial.println("Finished 1 stream");
    }else if(numActiveStreams == 2){
      int ind = 0;
      Serial.print("2 active streams");
      for(int i=0;i<numActiveStreams;i++){
        char strng[16];
        int idx = activeStreams[i];
        easyEngFltPrint(strng,dataStreamValues[idx]);
        //sprintf(strng,"%1.2f",dataStreamValues[idx]);
        int xe = glcd.drawBigString_24(0,2+i*3,strng,LCDWIDTH);
        xe+=2;
        glcd.drawBigString_24(xe,2+i*3,dataStreamUnits[idx],LCDWIDTH-1);
        Serial.print("Lab:");
        Serial.print(idx);
        Serial.print(">");
        Serial.println(&dataStreamLabels[idx][0]);
        xe =  5 + glcd.drawBigString_8(0,i,dataStreamLabels[idx],LCDWIDTH);
        
        if(numInfoStreams > i){
          xe += glcd.drawBigString_8(xe+2,i,dataStreamLabels[infoStreams[i]],LCDWIDTH);
          if(dataStreamIsStringVal[infoStreams[i]]){
            xe += glcd.drawBigString_8(xe+2,i,dataStreamStringVal[infoStreams[i]],LCDWIDTH);
          }else{
            char dstrng[32];
            easyEngFltPrint(dstrng,dataStreamValues[infoStreams[i]]);
            xe += glcd.drawBigString_8(xe+2,i,dstrng,LCDWIDTH);
          }
          xe += glcd.drawBigString_8(xe+2,i,dataStreamUnits[infoStreams[i]],LCDWIDTH);
        }
        ind++;
      }
    }else if(numActiveStreams == 3){
      Serial.print("3 active streams");
      for(int i=0;i<numActiveStreams;i++){
        char strng[16];
        int idx = activeStreams[i];
        easyEngFltPrint(strng,dataStreamValues[idx]);
        //sprintf(strng,"%1.2f",dataStreamValues[idx]);
        int xe = glcd.drawBigString_16(0,2+i*2,strng,LCDWIDTH);
        xe+=2;
        xe += glcd.drawBigString_8(xe,3+i*2,dataStreamUnits[idx],LCDWIDTH-1);
        Serial.print("Lab:");
        Serial.print(idx);
        Serial.print(">");
        Serial.println(&dataStreamLabels[idx][0]);
        xe+=2;
        xe += glcd.drawBigString_8(xe,3+i*2,dataStreamLabels[idx],LCDWIDTH);
        
        if(numInfoStreams > i){
          xe = glcd.drawBigString_8(0,i,dataStreamLabels[infoStreams[i]],LCDWIDTH);
          if(dataStreamIsStringVal[infoStreams[i]]){
            xe += glcd.drawBigString_8(xe+2,i,dataStreamStringVal[infoStreams[i]],LCDWIDTH);
          }else{
            char dstrng[32];
            easyEngFltPrint(dstrng,dataStreamValues[infoStreams[i]]);
            xe += glcd.drawBigString_8(xe+2,i,dstrng,LCDWIDTH);
          }
          xe += glcd.drawBigString_8(xe+2,i,dataStreamUnits[infoStreams[i]],LCDWIDTH);
        }
      }
    }else{
      Serial.println(">3 active streams");
      int mult = 3;
      if(numActiveStreams > 6){
        mult = 2;
        if(numActiveStreams > 8){
          Serial.println("Too many streams! showing 8");
        }
      }
      for(int i=0;i<numActiveStreams;i++){
        char strng[16];
        int idx = activeStreams[i];
        sprintf(strng,"%s:",dataStreamLabels[idx]);
        int zeroX = (i%2==0) ? 0 : 63;
        glcd.drawString(zeroX,mult*(i/2),strng,LCDWIDTH);
        easyEngFltPrint(strng,dataStreamValues[idx]);
        int xe = zeroX + glcd.drawBigString_8(zeroX, mult*(i/2)+1 ,strng,LCDWIDTH);
        xe+=2;
        xe += glcd.drawString(xe,mult*(i/2) + 1,dataStreamUnits[idx],LCDWIDTH);
      }
    }
    //glcd.drawBigString_48(0,1,&str2[2],LCDWIDTH);
    Serial.println("End of loop actions");
    glcd.st7565_set_brightness(0x17);
    delay(5);
    glcd.display();
    glcd.st7565_set_brightness(0x20);
    delay(10);
    glcd.st7565_set_brightness(0x1B);
    Serial.println("Disp updated");
  }/*else{
    char strng[8];
    for(int i=0;i<8;i++){
      strng[i] = (char) ((((millis()/2000) % 8)*8)+i+64);
    }
    int xe = glcd.drawBigString(0,4,strng,LCDWIDTH);

    glcd.st7565_set_brightness(0x17);
    delay(5);
    glcd.display();
    glcd.st7565_set_brightness(0x20);
    delay(10);
    glcd.st7565_set_brightness(0x1B);
    //xe+=2;
    //glcd.drawBigString(xe,2+i*3,dataStreamUnits[idx],LCDWIDTH-1);
  }*/

  if(digitalRead(PIN_I) == LOW){
    digitalWrite(BACKLIGHT_LED,HIGH);
  }else{
    digitalWrite(BACKLIGHT_LED,LOW);
  }
}
//15->I
//14->II
//13->L
//12->R
#define NUMFLAKES 10
#define XPOS 0
#define YPOS 1
#define DELTAY 2

void testdrawbitmap(const uint8_t *bitmap, uint8_t w, uint8_t h) {
  uint8_t icons[NUMFLAKES][3];
  randomSeed(666);     // whatever seed
 
  // initialize
  for (uint8_t f=0; f< NUMFLAKES; f++) {
    icons[f][XPOS] = random(128);
    icons[f][YPOS] = 0;
    icons[f][DELTAY] = random(5) + 1;
  }

  while (1) {
    // draw each icon
    for (uint8_t f=0; f< NUMFLAKES; f++) {
      glcd.drawbitmap(icons[f][XPOS], icons[f][YPOS], logo16_glcd_bmp, w, h, BLACK);
    }
    glcd.display();
    delay(200);
    
    // then erase it + move it
    for (uint8_t f=0; f< NUMFLAKES; f++) {
      glcd.drawbitmap(icons[f][XPOS], icons[f][YPOS],  logo16_glcd_bmp, w, h, 0);
      // move it
      icons[f][YPOS] += icons[f][DELTAY];
      // if its gone, reinit
      if (icons[f][YPOS] > 64) {
	icons[f][XPOS] = random(128);
	icons[f][YPOS] = 0;
	icons[f][DELTAY] = random(5) + 1;
      }
    }
  }
}
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

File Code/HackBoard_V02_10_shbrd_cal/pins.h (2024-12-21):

#ifndef PINS_H
#define PINS_H

#define ADC_CS 17
#define PGA_CS 20
#define ADC_MCLK 3

#define SR_RCK 13
#define SPI1_SCK 10
#define SPI1_MOSI 11
#define SPI1_MISO 12
#define RADIO_CS 14
#define RADIO_DO0 15
#define INMOD_CS 7
#define ONEWIRE 6
#define ONEWIRE_BRD 2

#define SDA_PIN 8
#define SCL_PIN 9

#define U0TX 0
#define U0RX 1
#define MTX 4
#define MRX 5

#define BATTERY_EN 22
#define D5V_ISO_EN 21

#define D5V_ISO_SENSE_ANIN 26
#define D5V_ISO_SENSE_CAL (((double)840)/330)
#define HV_SENSE_ANIN 27
#define HV_SENSE_ANIN_CAL (((double)133)/33)
#define VBAT_SENSE_ANIN 28 
#define VBAT_SENSE_ANIN_CAL (((double)840)/330)

#define ATTEN_147_SRPIN 8
#define ATTEN_11_SRPIN 9

#define OHM_PATH_DIS_SRPIN 0
#define OHM_BOOST_EN_SRPIN 1
#define OHMS_510_SRPIN 3
#define OHMS_10K_SRPIN 5
#define OHMS_100K_SRPIN 2
#define OHMS_1M_SRPIN 4
#define OHMS_LOWV_EN_SRPIN 6
#define OHMS_ELOWV_EN_SRPIN 19

#define MODULE_IN23SW_SRPIN 20

#define SWITCH_SRPIN_OHMS     0x0008
#define SWITCH_SRPIN_MA       0x0080

#define SWITCH_SRPIN_SW0      0x4000
#define SWITCH_SRPIN_SW1_UP   0x0800
#define SWITCH_SRPIN_SW1_DN   0x1000
#define SWITCH_SRPIN_SW2_UP   0x0200
#define SWITCH_SRPIN_SW2_DN   0x0400
#define SWITCH_SRPIN_SW3_UP   0x0010
#define SWITCH_SRPIN_SW3_DN   0x0100
#define SWITCH_SRPIN_SW4_UP   0x0040
#define SWITCH_SRPIN_SW4_DN   0x0020
#define SWITCH_SRPIN_SW6_UP   0x0001
#define SWITCH_SRPIN_SW6_DN   0x2000
#define SWITCH_SRPIN_SW7      0x0002
#define SWITCH_SRPIN_SW8      0x0004
#endif

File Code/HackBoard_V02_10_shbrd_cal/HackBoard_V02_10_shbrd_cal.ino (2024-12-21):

#include <SPI.h>
#include "pins.h"
#include "MCP436X.h"
#include "calibration.h"
#include "genVar.h"
#include "debug.h"
#include "meterState.h"
#include "fnList.h"
#include "shiftReg.h"
#include "pga.h"
#include "globals.h"
#include "squarewave.h"
#include "IIRFilter.h"
#include "movingAvg.h"
#include "backup1.h"
#include <nrf24.h>



MCP436X mainAdc(ADC_CS);

//BIG outstanding parts:
/*
3)switch matrix to output different genVars
4)Make genvars work good.  Main thing is cal fns.
*/

//operation = what the meter is doing (i.e. "measure voltage" is an operation
//function is used in the programming sense.  
//main loop executes a series of selection functions, which configure the meter and execute an or several operations

IIR iir180HzV(1200,180,10);
IIR iir120HzV(1200,120,10);
IIR iir60HzV(1200,60,10);
movingAvgf rmsAccum;
nrf24 nrfRadio(RADIO_DO0,RADIO_CS);//ce,cs
const uint64_t pipes[2] = { 0xE7E7E7E7E7LL, 0xC2C2C2C2C2LL };
//const uint64_t pipe = 0xC2C2C2C2C2LL;

//boolean alwaysFalse = false;
boolean alwaysFalse1 = false;
boolean alwaysFalse0 = false;
//boolean alwaysTrue = true;
boolean alwaysTrue1 = true;
boolean alwaysTrue0 = true;

//c0=core0  and (surprise!) c1=core1
//namespaces are used to separate core fns
//functions are hardcoded to one core or another

//core0 handles sampling and "real time" stuff (this doesn't run an
//actual RTOS, but we're shooting for decent sampling speed).  

//core1 handles "slow"/non-"real-time" operations, shift regs, serial, UI, etc.
namespace c1{
	void interpSwitches();
  void onBrdAnalogRead();
	void setVState();
	void setIState();
	void setRState();
	void disableR();
	void printState();
	void printV();
	void printVAC();
	void printI();
	void printR();
	void printRI();
	void printMod();
	void radioLoopFn(); 
	void serialRxHandler();
  boolean isOnBattery = false;
  uint32_t timeStOnBattery = 0;
};

namespace c0{
	void configADC();
	void readADCSingle();

	void prepForRSample();
	void setRMuxChannel();
	void setRPGAGain();
	void applyRICal();

	void prepForVSample();
	void setVMuxChannel();
	void setVPGAGain();
	void applyVCal();

	void prepForIHighSample();
	void prepForILowSample();
	void setIMuxChannel();
	void setIPGAGain();
	void applyICal();
	
	void prepForM0Sample();
	void prepForM1Sample();
	void setModPGAGain();
	void setMod0MuxChannel();
	void setMod1MuxChannel();
	void applyM0Cal();
	void applyM1Cal();
};


void configLoopFunctions(){
	//global state copy should always come first
	fnListAdd(   fnList_t{&copyC0Global,    &alwaysTrue0,          "c0tg"});
	secFnListAdd(fnList_t{&copyC1Global,    &alwaysTrue1,          "c1tg"});
	
	
	fnListAdd(fnList_t{&c0::configADC,      &alwaysTrue0,          "ADCc"});
	fnListAdd(fnList_t{&c0::setVMuxChannel, &c0g::voltsIsActive,   "vmux"});
	fnListAdd(fnList_t{&c0::setVPGAGain,    &c0g::voltsIsActive,   "vpga"});
	fnListAdd(fnList_t{&c0::prepForVSample, &c0g::enableVSample,   "vpre"});
	fnListAdd(fnList_t{&c0::readADCSingle,  &c0g::enableVSample,   "vadc"});
	fnListAdd(fnList_t{&c0::applyVCal,      &c0g::voltsIsActive,   "vcal"});

	fnListAdd(fnList_t{&c0::setRMuxChannel, &c0g::ohmsIsActive,    "rmux"});
	fnListAdd(fnList_t{&c0::setRPGAGain,    &c0g::ohmsIsActive,    "rpga"});
	fnListAdd(fnList_t{&c0::prepForRSample, &c0g::enableRSample,   "rpre"});
	fnListAdd(fnList_t{&c0::readADCSingle,  &c0g::enableRSample,   "vohm"});
	fnListAdd(fnList_t{&c0::applyRICal,     &c0g::ohmsIsActive,    "rcal"});
	
	fnListAdd(fnList_t{&c0::setIMuxChannel, &c0g::ampsIsActive,      "imux"});
	fnListAdd(fnList_t{&c0::setIPGAGain,    &c0g::ampsIsActive,      "ipga"});
	fnListAdd(fnList_t{&c0::prepForILowSample, &c0g::enableILowSample,  "ilpr"});
	fnListAdd(fnList_t{&c0::prepForIHighSample, &c0g::enableIHighSample, "ihpr"});
	fnListAdd(fnList_t{&c0::readADCSingle,  &c0g::enableILowSample,  "iadl"});
	fnListAdd(fnList_t{&c0::readADCSingle,  &c0g::enableIHighSample, "iadh"});
	fnListAdd(fnList_t{&c0::applyICal,      &c0g::ampsIsActive,      "ical"});

	fnListAdd(fnList_t{&c0::setMod0MuxChannel, &c0g::mod0IsActive,   "m0mx"});
	fnListAdd(fnList_t{&c0::setModPGAGain,     &c0g::mod0IsActive,   "m0pg"});
	fnListAdd(fnList_t{&c0::prepForM0Sample,   &c0g::mod0IsActive,   "m0pr"});
	fnListAdd(fnList_t{&c0::readADCSingle,     &c0g::mod0IsActive,   "m0ad"});
	fnListAdd(fnList_t{&c0::applyM0Cal,        &c0g::mod0IsActive,   "m0cl"});
	
	fnListAdd(fnList_t{&c0::setMod1MuxChannel, &c0g::mod1IsActive,   "m1mx"});
	fnListAdd(fnList_t{&c0::setModPGAGain,     &c0g::mod1IsActive,   "m1pg"});
	fnListAdd(fnList_t{&c0::prepForM1Sample,   &c0g::mod1IsActive,   "m1pr"});
	fnListAdd(fnList_t{&c0::readADCSingle,     &c0g::mod1IsActive,   "m1ad"});
	fnListAdd(fnList_t{&c0::applyM1Cal,        &c0g::mod1IsActive,   "mqcl"});

////////////////////////////////////////////////////////////////////////////////
	secFnListAdd(fnList_t{&readSwitches,    &alwaysTrue1,          "rdsw"});
	secFnListAdd(fnList_t{&c1::interpSwitches, &alwaysTrue1,       "itsw"});
  secFnListAdd(fnList_t{&c1::onBrdAnalogRead, &alwaysTrue1,      "anrd"});

	secFnListAdd(fnList_t{&c1::setVState,   &c1g::voltsIsActive,   "vsta"});
	secFnListAdd(fnList_t{&c1::setRState,   &c1g::ohmsIsActive,    "rst"});
	secFnListAdd(fnList_t{&c1::disableR,    &c1g::disableRPath,    "disR"});
	secFnListAdd(fnList_t{&c1::setIState,   &c1g::ampsIsActive,    "ista"});
	
	secFnListAdd(fnList_t{&c1::printV,      &c1g::doSendDisplayVoltage,    "prtV"});
	secFnListAdd(fnList_t{&c1::printVAC,    &c1g::doSendDisplayVoltageAC,  "prVA"});
	secFnListAdd(fnList_t{&c1::printI,      &c1g::doSendDisplayCurrent,    "prtI"});
	secFnListAdd(fnList_t{&c1::printR,      &c1g::doSendDisplayResistance, "prtR"});
	secFnListAdd(fnList_t{&c1::printRI,     &c1g::doSendDisplayTestCurrent,"prRI"});
	secFnListAdd(fnList_t{&c1::printMod,    &c1g::doSendDisplayMod,        "prtM"});
	secFnListAdd(fnList_t{&c1::printState,  &alwaysTrue1,                  "prtS"});

	secFnListAdd(fnList_t{&writeSRPins,        &alwaysTrue1,           "srpn"});
	secFnListAdd(fnList_t{&c1::radioLoopFn,    &alwaysTrue1,           "rdlp"});
	secFnListAdd(fnList_t{&c1::serialRxHandler,&alwaysTrue1,           "seRX"});
}
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
